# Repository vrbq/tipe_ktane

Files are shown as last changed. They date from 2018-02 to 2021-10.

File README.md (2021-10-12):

# Bomb Defuse Game ! 
### (based on 'Keep Talking And Nobody Explodes')

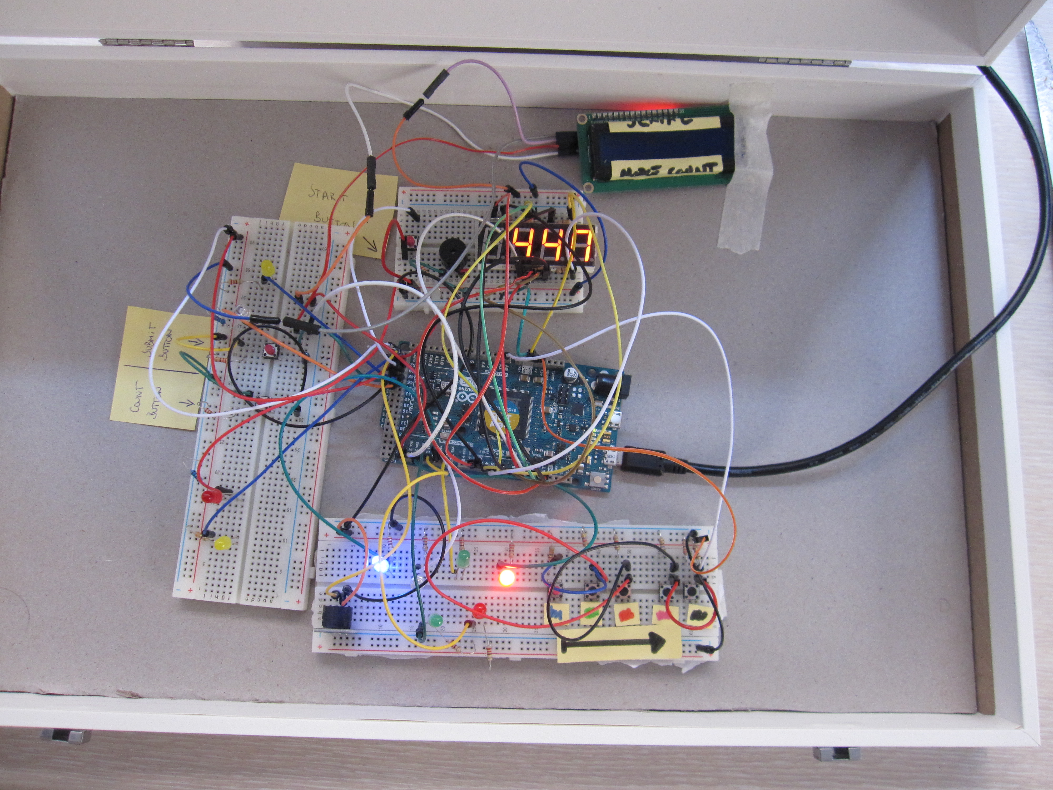
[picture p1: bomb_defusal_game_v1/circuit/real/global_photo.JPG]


## Dependencies

- [AnalogMultiButton](https://github.com/dxinteractive/AnalogMultiButton)
- [LiquidCrystal_I2C](https://github.com/marcoschwartz/LiquidCrystal_I2C)
- [SevSeg](https://github.com/sparkfun/SevSeg)

## Building the circuit

- Global Circuit

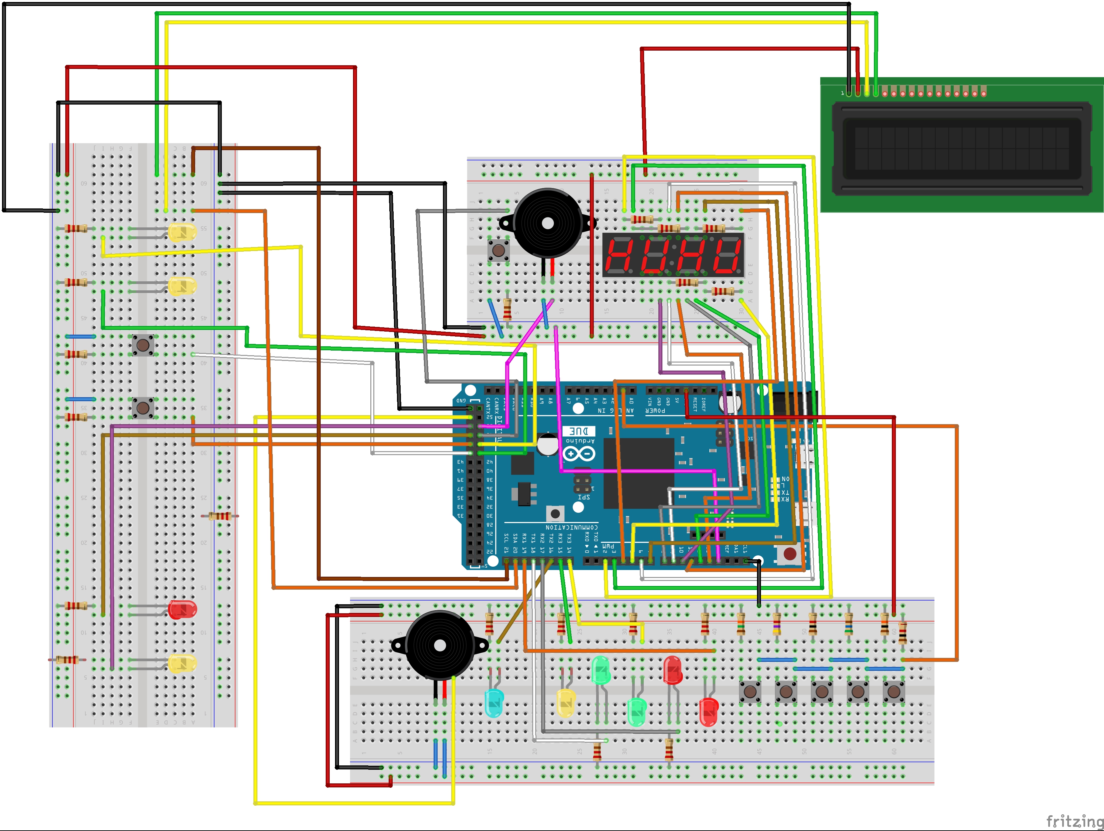
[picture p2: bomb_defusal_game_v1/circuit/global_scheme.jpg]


## Playing

- It's a coop game.

- One player is in front of the bomb but does not see it, while the other communicates the instructions to defuse it.

- For more information, see "manuel" folder.

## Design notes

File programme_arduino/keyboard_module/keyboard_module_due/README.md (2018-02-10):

# Keyboard module for the bomb defuse game

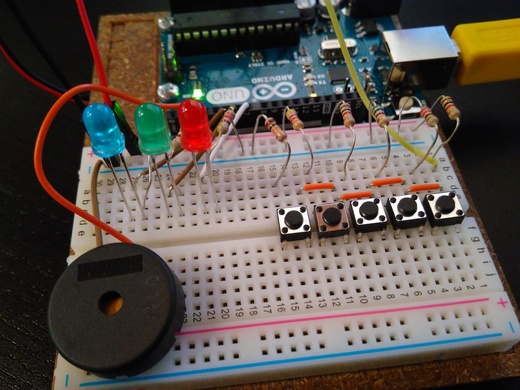
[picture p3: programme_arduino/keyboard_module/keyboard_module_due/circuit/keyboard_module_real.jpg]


A video of the module in action can be found [here](https://youtu.be/Le4A3sgtfqI)!

## Dependencies

- [AnalogMultiButton](https://github.com/dxinteractive/AnalogMultiButton)

## Building the circuit

See the circuit layout in `circuit/circuit.png`.

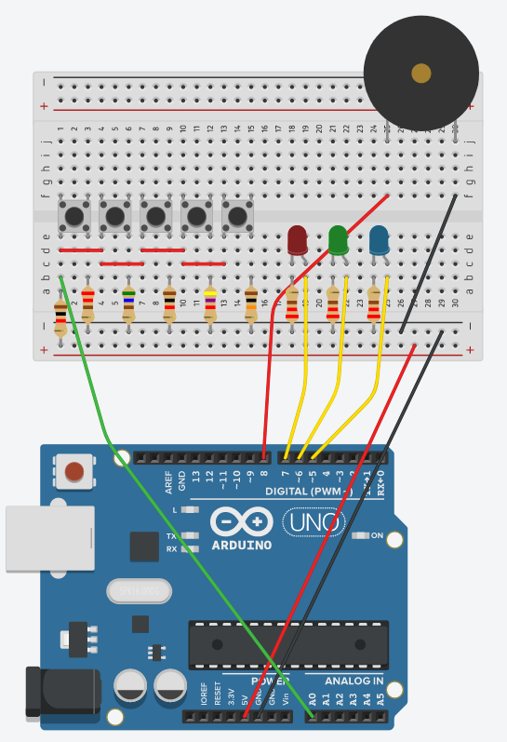
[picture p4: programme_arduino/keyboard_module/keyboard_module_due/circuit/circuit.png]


Alternatively, you can view the circuit on [Tinkercad](https://tinkercad.com). Search for 'defuse_keyboard_module' to find the circuit.

Unfortunately, because the Tinkercad simulator does not allow to import external libraries (AnalogMultiButton in our case), it is not possible to simulate the module there.

## Playing

- At startup, an initialization sequence is played (all LEDs blink sequentially three times in a row).

- A random code is selected in the database (see file `Keyboard.h`), and displayed in coded form to the defuser through a combination of color LEDs.

- A random shift is selected, and displayed in coded form through a combination of color LEDs.

- The defuser has to press every single note in the code correctly, in the right order. If a note is wrong, the red LED will be triggered with a double beep. In that case, the user has to start again from scratch.

## TODO

- Generate documents that indicate the mapping between combinations of color LEDs and code / shift.

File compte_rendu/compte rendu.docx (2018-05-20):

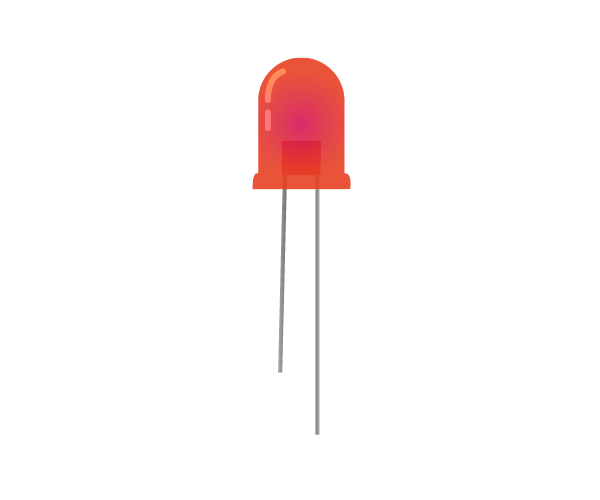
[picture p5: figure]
RÃ©sultat de recherche d'images pour "led"

2017-2018

Rapport de TIPE

NAHMIAZ Thomas REBECQ Victor

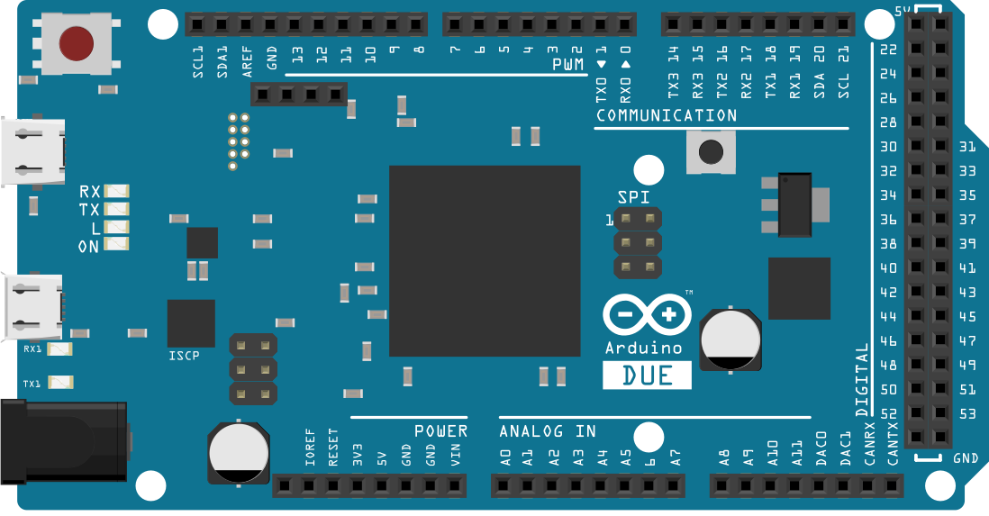
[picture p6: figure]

Est-il possible de faire un jeu sous Arduino ?

PTSI 1

# Résumé :

Le projet proposé est un jeu physique sur Arduino. Le principe est de désamorcer une bombe, en équipe de deux joueurs ou plus. Deux équipes coopéreront lors du jeu :

Le démineur : il peut voir la bombe, interagir avec elle mais ne connait pas le procédé pour désamorcer la bombe.

Les experts : ils possèdent un manuel qui permettra de résoudre les énigmes, mais ne peuvent pas interagir physiquement ou voir la bombe.

Ce jeu est donc purement coopératif, où la communication est primordiale. Les différents mini-jeux doivent être résolus dans un ordre quelconque mais un temps imparti de 5 minutes. Au-delà de ce temps ou si les joueurs font plus de 2 fautes, la bombe explosera.

# Introduction :

Premièrement nous aborderons la mise en place des idées à propos du projet, ses premières maquettes physiques ainsi que les exigences du projet. Puis, nous montrerons comment nous avons procédé pour obtenir plusieurs mini-jeux, jouable en même temps sur Arduino.
Enfin, nous réaliserons un ensemble de tests, et nous évaluerons comment le projet pourra désormais évoluer.

# I. Mise en place :

## Naissance du projet

Dès fin septembre, nous avions trouvé notre projet de TIPE : nous voulions tous les deux faire un jeu, jouable physiquement (avec des boutons, LEDs,…). Après réflexion, et après avoir joué à la version ordinateur de Keep Talking and Nobody Explodes (http://www.keeptalkinggame.com/), nous avons été convaincus que c’est ce jeu que nous voulions adapter physiquement.

Le principe du jeu est simple : 2 joueurs sont en équipe, et doivent désamorcer une bombe, composée d’énigmes. Un joueur voit la bombe, peut interagir avec elle mais ne connait pas la solution aux énigmes (appelés « Modules » dans la suite). L’autre joueur possède le manuel avec la procédure permettant de désamorcer chaque module, mais ne peut ni voir, ni toucher la bombe. C’est ce mélange de jeu coopératif, mêlant tensions et incompréhension, qui nous a montré le potentiel que pouvait avoir ce concept.

## Première maquette

Il fallait désormais prouver que ce concept était viable et réalisable.
Après une première explication orale, nous nous sommes heurtés à un avis plutôt mitigé. En effet, le concept est peut-être facile à comprendre mais il était dur de voir si cette idée pouvait devenir un « jeu », et non rester une banale résolution d’énigme à 2.

Nous avons donc réalisé une maquette en carton de la bombe. Nous avons conçu 4 premiers modules (respectivement le module « Bouton », « Morse », « Accéléromètre » et « Films »).
Un chemin précis (et unique, le jeu était difficilement rejouable) avait été déterminé. Pendant que l’un de nous deux faisait tourner les disques en carton attachés avec des attaches parisiennes, l’autre vérifiait que les modules étaient correctement réalisés, indiquait le temps restant, comptait les erreurs, ... C’est la première prise de conscience que le point important de ce sujet allait être de pouvoir rendre notre programme « multi-tâche ».

Avec cette maquette, nous avons effectué une dizaine d’expérimentations et tiré plusieurs enseignements :

- Premièrement, le jeu n’avait un intérêt que s’il y avait une certaine pression, ajoutée par la limite de temps. Sans elle, le jeu aurait été dénué d’intérêt.
- Ensuite, malgré les défauts apparents d’un tel système, ainsi que la grossièreté de la maquette, chaque groupe de personne testé (avec une limite de temps donc) eu un certain plaisir, une certaine envie de recommencer et de réussir. Cette maquette a d’ailleurs plutôt convaincu M.Delegue (qui faisait équipe avec M. Prachay).

Alors, confiants sur l’avenir du projet, nous nous sommes lancés dans la réalisation du programme.

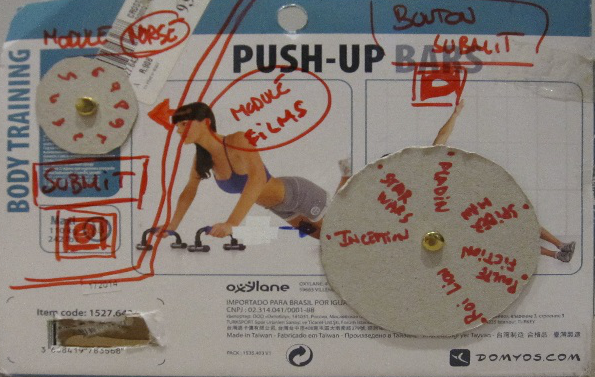
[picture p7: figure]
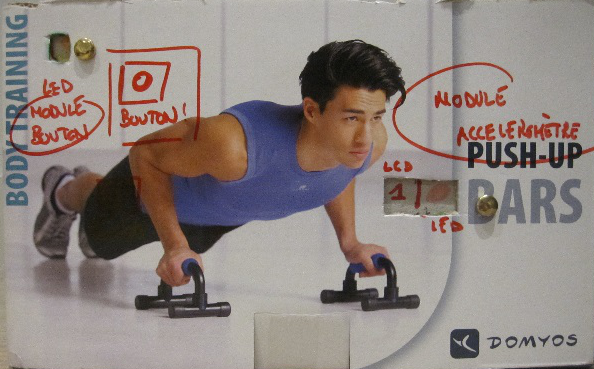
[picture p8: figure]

Figure 1 : Photo de la maquette de la bombe sur une boite en carton

## Lancement du projet, mise en place des exigences

En se basant sur nos idées nous avons conçu le cahier des charges suivant que nous avons suivit tout au long de l’année :

Exigences :

Faire un jeu : Priorité aux interactions entre les joueurs.

Utiliser le minimum d’entrées/sorties.

Gérer plusieurs modules en même temps.

Pouvoir émuler des sons.

Avoir un programme propre.

Pouvoir s’échanger des données facilement pendant le projet (entre concepteurs du projet).

Avoir un manuel propre et intuitif.

Faire un jeu réutilisable, rejouable.

Pouvoir ajouter d’autres modules facilement.

Utiliser un accéléromètre pour donner une vraie dimension physique au jeu.

Nous avons également mis en place un planning tout au long du projet afin de mieux nous organiser. Voir l’annexe 2 pour voir la représentation du planning sous forme de diagramme de GANTT.

# II. Conception :

## Création des modules :

Sans entrer dans une description fastidieuse du mini-jeu et/ou du programme, nous allons brièvement expliquer le principe de chaque module puis expliquer les principaux points de leur réalisation.

Module Keyboard

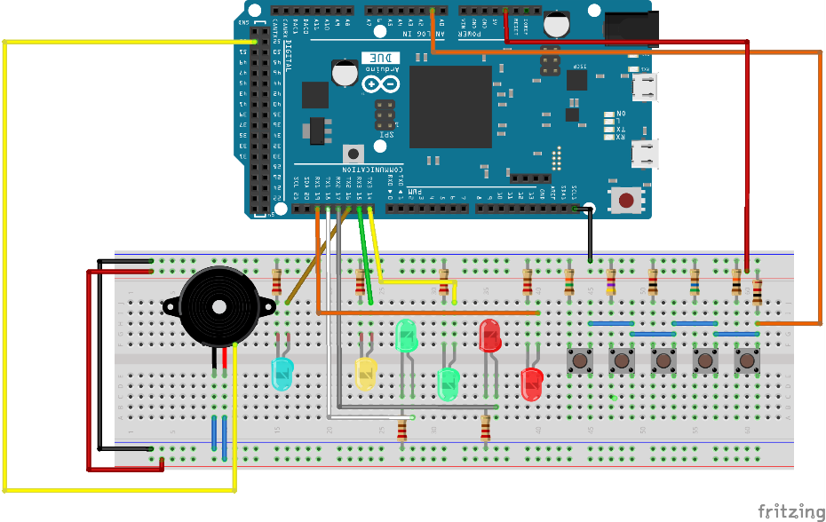
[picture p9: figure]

Figure 2 : Schéma du module Keyboard

Principe : Le démineur doit jouer une séquence précise composée de 9 notes. Les 2 paramètres à prendre en compte sont :

- Le positionnement du « DO », qui peut changer de place parmi les 5 boutons. Cette position est déterminée grâce à un code.
- La séquence à jouer, qui varie selon les couleurs des LEDs allumées.

2 principes assez fondamentaux sont intéressants à détailler ici :

- Emuler un son sous Arduino

Etant sur Arduino DUE (car plus grand nombre d’entrées/sorties )la fonction tone, grandement utilisée sous Arduino UNO ne peut pas être utilisé.

Nous avons donc dû chercher une fonction nous permettant d’émuler un son.

Figure 3 : Comparaison des caractéristiques entre Arduino UNO et DUE

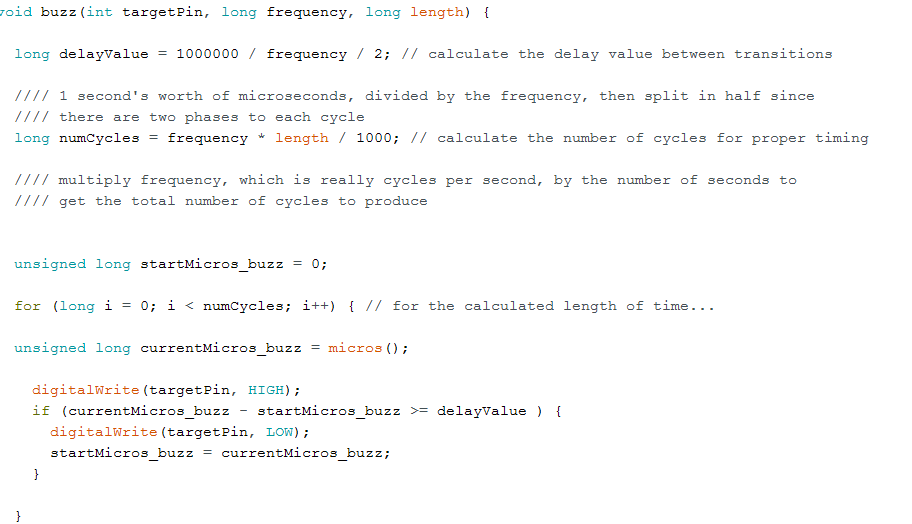
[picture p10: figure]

Figure 4: principe de la programmation du timer

Au-delà de trouver un programme qui fonctionne directement, il est intéressant de comprendre son fonctionnement.

3 attributs sont nécessaires pour cette fonction :

- La sortie du buzzer (buzzer actif, insérer une photo)
- La fréquence jouée (540 Hz pour un LA par exemple)
- La longueur de la note jouée

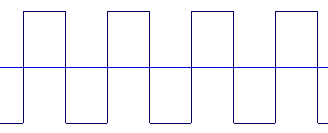
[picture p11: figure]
Résultat de recherche d'images pour "signal carré"

Figure 5 : Signal carré

- Ce programme simule en réalité un signal carré (proche du signal sinusoidal désiré).
- Dans un premier temps, le programme calcule la durée d’une période du signal carré (delayValue).
- Puis est calculé le nombre de cycles (numCycles) qui vont être nécessaire pour jouer le signal carré.
- Le « temps courant », juste avant de rentrer dans la boucle qui va émuler le signal carré, est noté start_Micros_buzz.
- Enfin, on entre dans une boucle qui passe dans l’état « Allumé » dès l’entrée dans cette boucle. Le temps courant est à chaque fois actualisé dans la variable currentMicros_buzz.
- Quand le buzzer aura été allumé plus de temps qu’une période (currentMicros_buzz - start_Micros_buzz >= delayValue) , il ne jouera plus de son. A ce moment, la variable start_Micros_buzz est réinitialisé.
- Cette boucle tournera autant de fois que nécessaire, c’est-à-dire autant de fois que numCycles.
- Boutons branchés en série

Une de nos contraintes étaient d’utiliser le moins d’entrées/sorties possibles. Ayant beaucoup de composants à brancher, nous ne pouvions pas utiliser 5 sorties uniquement pour les boutons. Nous avons donc utilisé une des sorties analogiques de l’arduino, puis branché en série les 5 boutons.

[Sortie 3.3V]

V

[2.2K résistance]

V

[Sortie analogique] --> Bouton 1 --> GND

V

[1K résistance]

+--> Bouton 2 --> GND

V

[1K résistance]

+--> Bouton 3 --> GND

V

[1K résistance]

+--> Bouton 4 --> GND

V

[1K résistance]

+--> Bouton 5 --> GND

Figure 6 : Diagramme d'utilisation d'Analog Multi Button (source : gitHub librairie AnalogMultiButton)

Arduino attribue une valeur analogique aux boutons branchés en série entre 0 et 1023.
Après quelques tests, on peut savoir quel bouton correspond à quelle valeur.
La librairie AnalogMultiButton nous permet alors d’associer ces valeurs à chaque bouton.

Figure 7 : Déclaration des boutons du module « piano »

Module Timer :

Pour ce module, nous avons utilisé un afficheur 7 segments

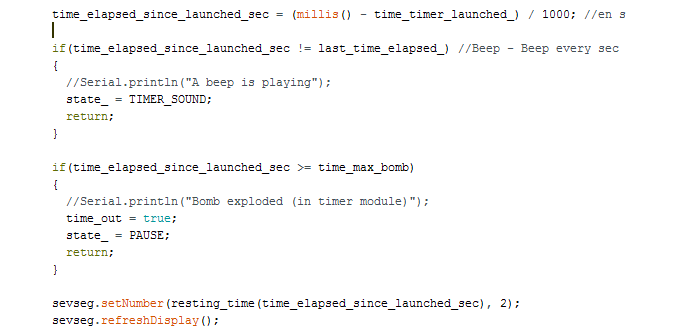
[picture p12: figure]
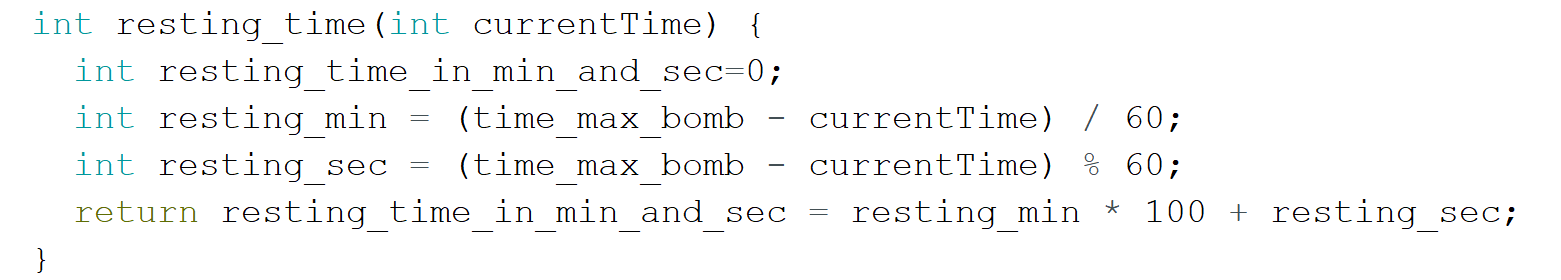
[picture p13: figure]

Figure 8 : Principes de la programmation du timer

Dès que la bombe est lancée, le temps courant est sauvegardé dans la variable time_timer_launched.
Ainsi est calculée le temps depuis lequel la bombe a été lancée (time_elapsed_since_launched_sec).
Avec une boucle Tant Que, on limite le temps d’écoulement du timer avec la variable préalablement définie time_max_bomb.

Enfin, l’afficheur 7 segment est rafraichi et affiche continuellement le temps restant. La fonction resting_time permet de séparer les minutes et les secondes, pour afficher ces 2 éléments distinctement sur l’afficheur.

Module Morse :

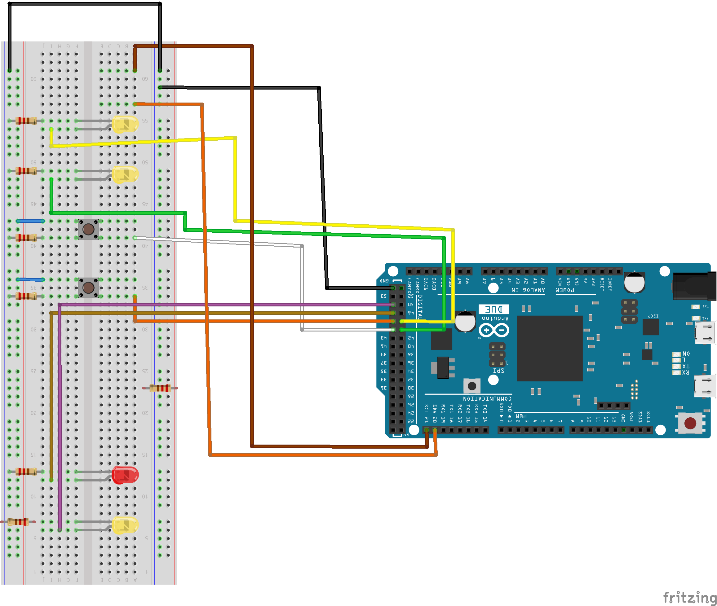
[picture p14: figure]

Principe: Le joueur devant la bombe doit communiquer des signaux qu’il voit en morse afin que l’autre joueur déchiffre le bon mot parmi neufs possibles.

Les mots sont directement convertis dans le programme afin de pouvoir changer facilement de mot sans erreurs. La fonction ToUpperCase transcrit les mots en majuscules pour avoir moins de lettres à coder, ensuite la fonction replace change toutes les lettres en suites de « . » et « - » selon le langage morse français. Il ne reste plus qu’à traduire les mots en signaux lumineux grâce à, entre autres, la fonction millis détaillée plus loin.

Figure 9 : Schéma du module Morse

Nous avons utilisé la commande switch case pour choisir le mot en fonction de la valeur apportée par la commande Randomseed : l’avantage de cette commande par rapport à un if .. else est de raccourcir et clarifier nettement la syntaxe.

Rebond du bouton :

L’appui sur un bouton poussoir peut ne pas transmettre qu’un seul contact mais plusieurs, dépendant de la qualité du bouton.

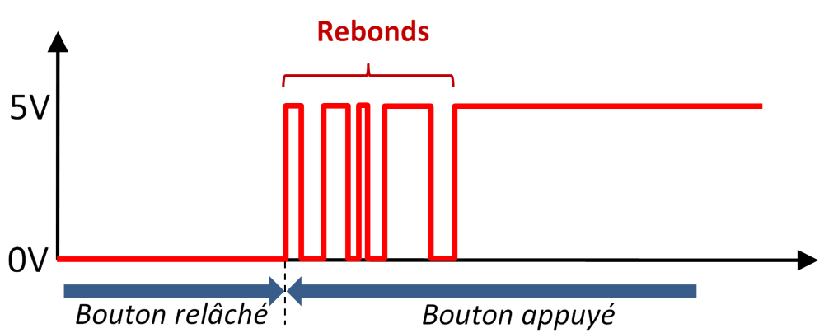
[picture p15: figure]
RÃ©sultat de recherche d'images pour "rebond bouton poussoir"

Figure 10: Schéma du signal émis par le rebond d'un bouton

Il y’a deux façons de résoudre ce problème :

Utiliser un condensateur en parallèle pour adoucir le passage transitoire ou attendre logiciellement un court instant (250 millisecondes) avant le décompte d’un autre appui sur le bouton pour être sûr de ne pas prendre en compte les rebonds. C’est la deuxième solution qui a été choisie.

Module accéléromètre

Il était prévu mais n’a pas été intégré dans le projet, faute de temps. Le joueur devait bouger un cube en fonction des indications de l’autre joueur. Ce module aurait rajouté une véritable dimension physique au jeu par rapport à un jeu virtuel. L’intention initiale était de faire des translations du cube dans l’espace. Or l’accéléromètre ne relève que l’accélération et l’orientation dans l’espace. Il n’était pas possible de relever avec précision les mouvements effectués. Nous avions donc adapté le manuel du démineur afin que le joueur doive effectuer des rotations du cube ce que l’accéléromètre permettait de faire avec plus de précision.

Une bibliothèque Arduino est dédiée à l’accéléromètre. Après avoir inclus la bibliothèque et initialisé l’accéléromètre il suffit de relever les valeurs relevées par celui-ci. Le joueur aurait dû mettre le cube dans la position indiquée par le manuel et appuyer sur un bouton pour relever la valeur des positions selon les axes X, Y et Z.

## Gérer plusieurs modules en même temps :

Voici la partie la plus compliquée que nous ayons eu à réaliser.

La fonction delay est une fonction bloquante qui ne permet pas d’effectuer plusieurs tâches en parallèle. Ainsi, à chaque émulation de son le programme se gelait entièrement (l’afficheur 7 segments était principalement impacté). Nous avons donc opté pour l’utilisation de la fonction millis qui gère le temps sans être une fonction bloquante selon le modèle :

Pour expliquer ce concept, voici un programme non bloquant :

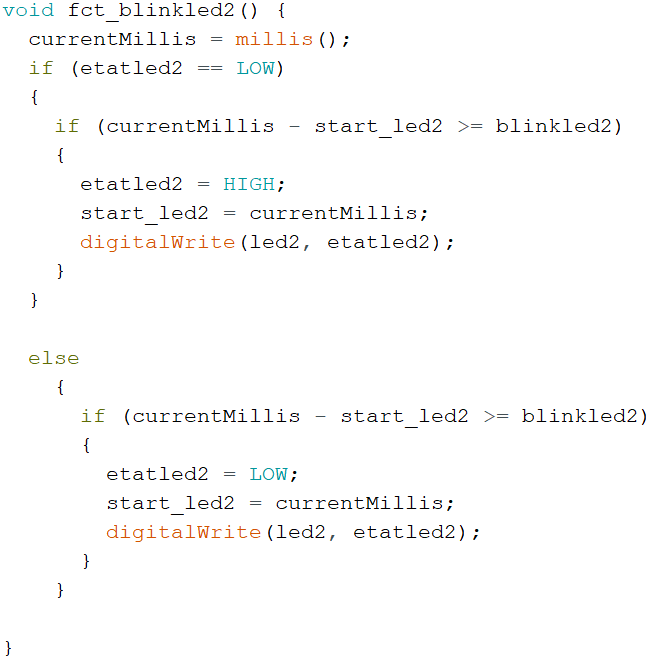
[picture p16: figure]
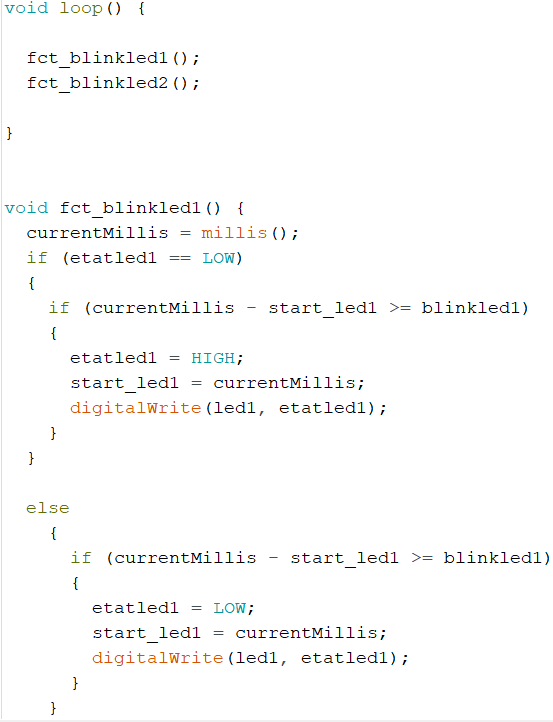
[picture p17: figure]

Figure 11 : Programme de deux Leds clignotant de manière désynchronisée

Ici, les 2 LEDs clignotent de manière complètement indépendante. Avec la fonction delay, il serait impossible de réaliser un tel programme.

Pour réaliser cela, nous avons contacté Henri Rebecq, frère de Victor, ingénieur diplômé de l’école Paris Telecom et travaillant actuellement sur sa thèse à l’ETH de Zurich. Nous n’avions aucune idée de comment réaliser cet assemblage de tous les modules, autant logiquement que techniquement (le langage Arduino étant proche du C, langage que nous ne connaissons pas bien).

Pour utiliser cette fonction millis, le programme a donc besoin de savoir – à chaque instant – dans quel état il se situe.

Pour cela, Henri nous a conseillé de réaliser une machine à état. Nous allons ici voir un exemple sur le module « Piano », sachant que les autres modules ont été réalisé d’une manière similaire (par souci de cohérence du programme).

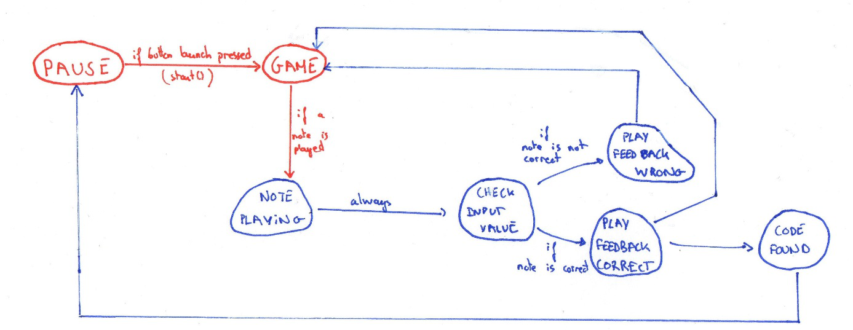
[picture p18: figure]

Figure 12 : Diagramme d'états du module Keyboard

Selon le diagramme ci-dessus, nous avions donc défini plusieurs états :

- PAUSE : état initial du module. Lorsque la fonction reset est appelé (par l’appui d’un bouton par exemple), l’état passe à GAME.
- GAME : état principal, où l’appui sur un bouton est détecté. Plusieurs sous-états se suivent :
  - NOTE_PLAYING : suit directement l’état GAME ; permet de jouer directement la note correspondant au bouton venant d’être appuyé
  - CHECK_INPUT_VALUE : traite l’entrée du bouton (entrée correcte ou fausse).
  - PLAY_FEEDBACK_CORRECT : allume une LED verte.
  - PLAY_FEEDBACK_WRONG : allume une LED rouge et recommence le code à zéro.
  - CODE_FOUND : Le jeu revient à son état initial (PAUSE)

Le même principe a été appliqué pour le module « Morse ou « Timer ». (voir annexe 2).

La fonction attachInterrupt permet d’arriver au même résultat. A chaque appui sur un bouton celle-ci effectue une tâche en priorité sur les autres. Cette fonction n’est cependant pas durable sur des programmes longs et ne peut pas être utilisée un grand nombre de fois en tant qu’une seule fonction ne peut être appelée dans le même temps.

Henri nous a aussi conseillé d’améliorer la lisibilité de notre programme. Pour cela, nous avons mis nos variables dans la même casse : en anglais, sans majuscule, avec un underscore. Nous avons aussi réalisé nos modules dans la même idée (machines à états appelant les mêmes états principaux : PAUSE et GAME).

## Faire un jeu réutilisable :

### Solutions :

Nous avons décidé d’utiliser des valeurs aléatoires et de programmer plusieurs chemins possibles en fonctions de ces valeurs pour que le jeu présente différents cas et qu’ainsi les parties de soient pas répétitives. Ces différents chemins se feront directement à l’intérieur du module comme pour le morse ou au travers du numéro de série. Les chemins changent à chaque redémarrage de la carte pour proposer des parties différentes.

### Mise en œuvre :

Nous avons utilisé la fonction random(min, max) pour générer des variables aléatoires. Il est à noter que la valeur minimale est incluse et que la valeur maximale est exclue, c’est pourquoi dans le module morse pour neuf mots nous avons pris la valeur alea = random(1,10).

La fonction random ne génère qu’une valeur aléatoire par téléversement, et non pas à chaque redémarrage de la carte. Nous avons donc rajouté la fonction randomSeed(analogRead(0)) qui lit une grandeur physique sur la sortie 0 qui n’est branchée à rien. Cette fonction permet de générer une valeur aléatoire différente à chaque mise sous tension de la carte en plus d’obtenir des valeurs plus aléatoires.

## Outils informatiques utilisés :

Nous avons utilisé le site d’échange de données GitHub afin de réunir les programmes et autres fichiers dans un dossier en ligne. Cela permet le partage des programmes et d’autres fichiers afin de les ouvrir sur n’importe quel ordinateur ayant les droits d’accès au projet. Notre projet sur Github :

https://github.com/trickart73/tipe_ktane/tree/master/bomb_defusal_game_v1

Le logiciel Fritzing pour réaliser les schémas du projet, ce logiciel permet également de simuler un projet et de créer les plans en circuit imprimé. Un schéma du circuit est essentiel pour pouvoir communiquer aux autres comment comprendre et réaliser un certain programme.

Nous avons aussi utilisé l’hébergeur de vidéos YouTube pour partager les vidéos de test.

Enfin nous avons évidemment utilisé Arduino pour la programmation du projet

# III. Exploitation

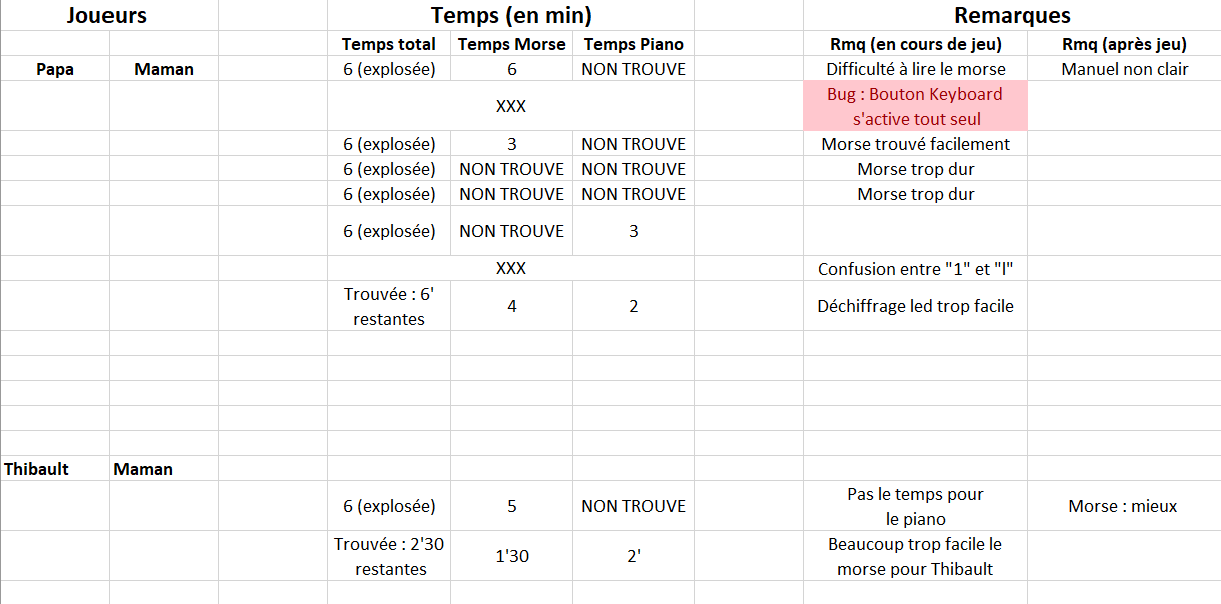
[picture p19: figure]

Nous avons réalisé plus d’une vingtaine de tests avec des binômes de personnes différente. Il a fallu au début trouver le juste milieu au niveau de la difficulté et corriger les bugs rencontrés.

Figure 13 : Compte rendu des premières parties jouées

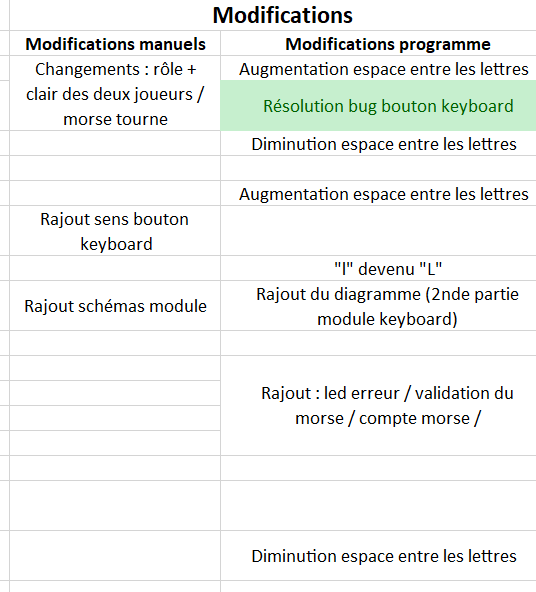
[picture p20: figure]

Nous voyons bien qu’au fur et à mesure des parties, les joueurs progressent.

Toutefois, les joueurs ayant testé le jeu ont été satisfaits et ont ressenti la frustration de la défaite des premières parties, leur donnant envie de rejouer.

Il est aussi important de noter que depuis ces 10 premières tentatives – où de nombreuses modifications ont été apportées au projet – aucun bogue (venant du programme ou de la conception des manuels) n’a été constaté. En effet, sur les 20 tentatives suivantes, le seul problème que nous ayons eu est un débranchement de fils (dû aux grands nombres de connexions).

Nous avons filmé le premier essai de M. Lanoix devant la bombe (disponible ici : https://www.youtube.com/watch?v=MbPvuHy70Hc&feature=youtu.be )

Figure 14 : Modifications apportées suites aux tests

# Conclusion :

Le cahier des charges du projet a en grande partie été rempli. Le jeu est désormais opérationnel.

Les cartes Arduino regorgent de possibilités et sont donc un bon support pour ce projet. En plus d’avoir une grande communauté, les accessoires électroniques sont peu chers et permettent de réaliser des maquettes facilement. Les cartes Arduino ont une grande capacité de calcul et de stockage étant donné que le code ne prend que très peu d’espace. Le programme que nous avons conçu n’occupe que 7% de la mémoire de la carte et permet donc un large développement du projet ultérieurement.

Pour finir, que peux devenir le projet ? Aujourd’hui, nous avons un jeu fonctionnel, comprenant 2 modules. Le jeu est grandement réutilisable avant de devenir facile.
De plus, nous avons réalisé l’ensemble des modules selon la même architecture, en utilisant des classes. Sans rentrer dans les détails de conception, cela nous a permis d’obtenir un fichier « main » court et propre, idéal de tout programme. Les autres modules sont réalisés dans des fichiers à part (les « headers », avec pour extension « .h »).

Nous pouvons donc rajouter facilement des modules, à l’unique condition qu’ils ne soient pas bloquants !
Dans la conception en elle-même, Arduino reste un prototypage, avec des plaques d’essais. Nous pourrions facilement envisager de remplacer chaque module par un circuit imprimé, qui peut facilement se rajouter au jeu. Nous pourrions aussi rajouter une boîte plus adaptée, ou encore une batterie externe, ou un système de difficulté (Facile ou Difficile), car nous avons remarqué durant les phases tests que la difficulté n’était pas ressentie de la même manière pour un étudiant en sciences qu’un étudiant en lettres (des calculs parfois conséquents peuvent être effectués).

Enfin, si nous décidons d’améliorer ce TIPE par la suite, nous pourrions aussi le porter sur Arduino UNO (avec l’aide d’un 74HC595, permettant de démultiplier le nombre de sorties/entrées sur l’Arduino). Techniquement parlant, l’Arduino Uno serait largement capable de recevoir et d’exécuter un tel programme.
L’ultime étape serait d’utiliser un microcontrôleur (chipset) : l’Arduino ne deviendrait alors utile que pour téléverser le programme (interface chipset / ordinateur).

## Remerciements

Nous remercions bien évidemment nos 2 professeurs, M. Lanoix et M. Delegue, qui nous ont guidé tout du long de ce projet. Un grand merci à Henri Rebecq, sans qui nous n’aurions pu réaliser ce projet tant son aide a été précieuse. Les connaissances qu’il nous as transmises - tant la logique et le raisonnement de construction d’un programme complexe, que des outils techniques comme les classes – nous seront certainement utile pour le reste de nos années de programmeur. Un merci aux parents (qui ont toujours été les premiers testeurs de versions pas toujours très abouties) et à tous ceux qui ont pu tester le jeu, leurs retours sont indispensables à l’amélioration du jeu.

# Bibliographie :

- CFaury, « Le bouton poussoir », http://arduino.blaisepascal.fr/index.php/2017/11/30/le-bouton-poussoir/, 02/18
- WMLogistic, « Code Morse avec une Led », https://forum.arduino.cc/index.php?topic=492308.0, 12/17
- TamiaLab, « Faire plusieurs choses à la fois avec une carte Arduino », https://www.carnetdumaker.net/articles/faire-plusieurs-choses-la-fois-avec-une-carte-arduino/, 03/18
- David LeGall, « Un minuteur à base d'Arduino », http://wikifab.org/wiki/Timer_:_Un_minuteur_%C3%A0_base_d%27Arduino, 11/17
- Coding Badly, « The reliable but not very sexy way to seed random », http://forum.arduino.cc/index.php/topic,66206.0.html, 01/18
- Rob Faludi, « Buzzer Arduino Example Code », https://www.faludi.com/2007/04/23/buzzer-arduino-example-code/, 12/17
- Dxinteractive, « AnalogMultiButton », https://github.com/dxinteractive/AnalogMultiButton, 01/18

# Annexes

Annexe 1

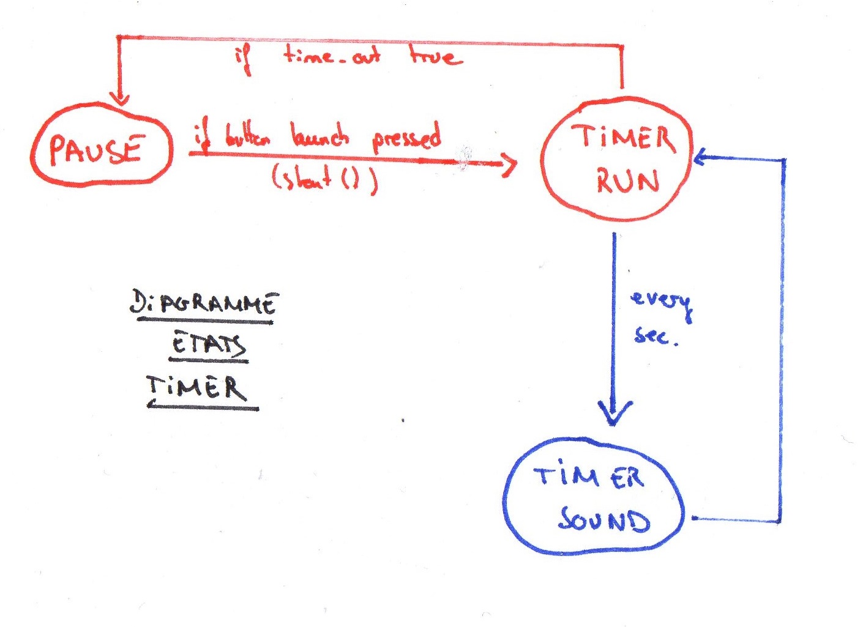
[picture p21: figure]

Figure 15 : Diagramme d'états Timer

Annexe 2 :

Figure 16: Planning (GANTT)

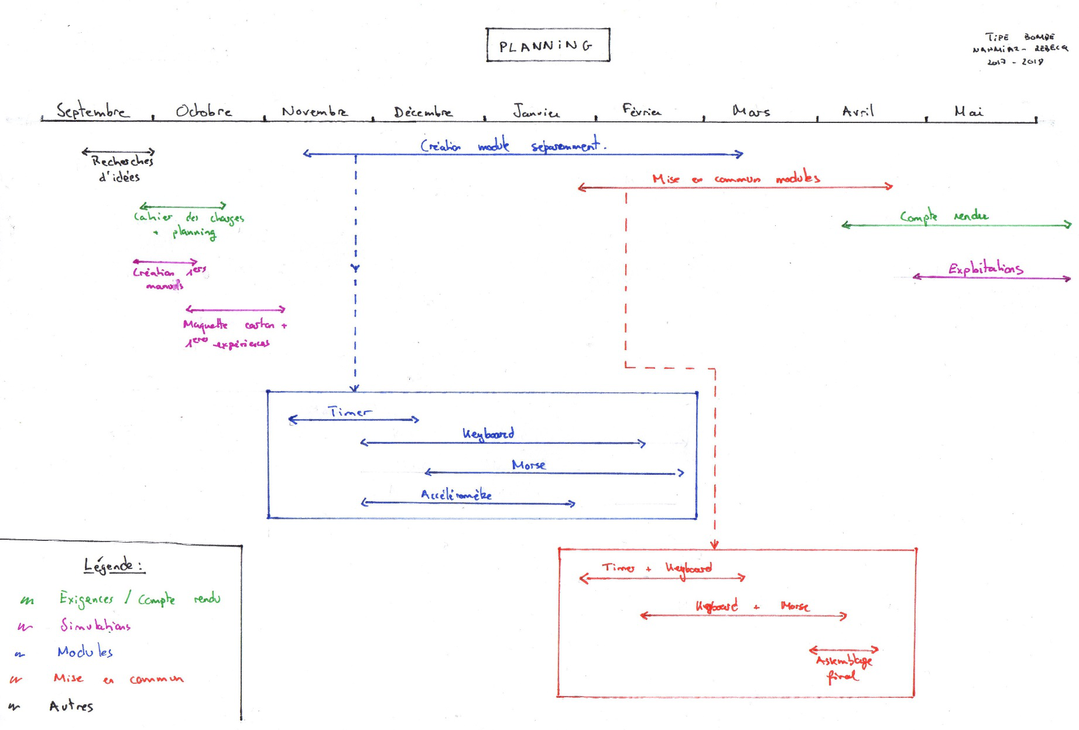
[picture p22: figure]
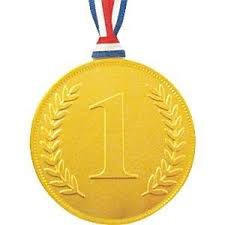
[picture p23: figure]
C:\Users\Vic\AppData\Local\Microsoft\Windows\Temporary Internet Files\Content.MSO\58AD7BD0.tmp

Annexe 3 :

Clémence Potin & Antoine Vermorel

(temps restant : 52 secondes)

A l’heure actuelle, un seul duo à réussi à désamorcer la bombe en 5 minutes dans les conditions suivantes :

- Pas de triche
- Aucune aide des créateurs du jeu

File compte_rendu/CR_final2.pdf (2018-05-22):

# 2017-2018 Rapport de TIPE NAHMIAZ Thomas, REBECQ Victor

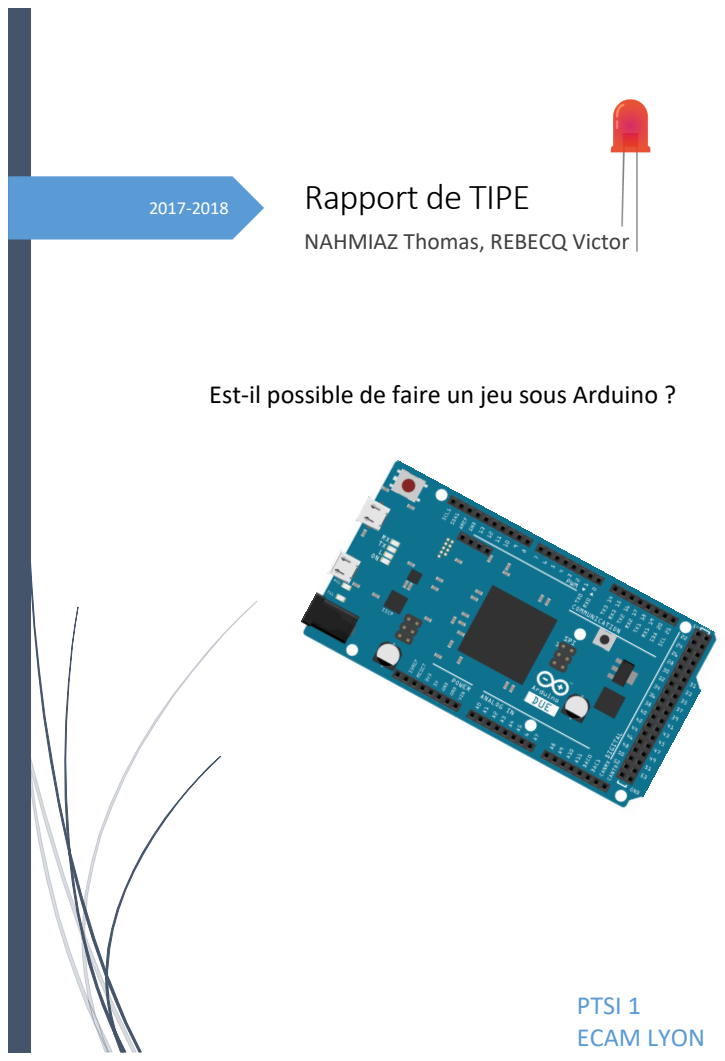
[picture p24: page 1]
PTSI 1 ECAM LYON

Est-il possible de faire un jeu sous Arduino ?

TIPE 2017-2018

## Table des matières

## Résumé :

Le projet proposé est un jeu physique sur Arduino. Le principe est de désamorcer une bombe, en équipe de deux joueurs ou plus. Deux équipes coopéreront lors du jeu :

- Le démineur : il peut voir la bombe, interagir avec elle mais ne connaît pas le procédé pour désamorcer la bombe.
- Les experts : ils possèdent un manuel qui permettra de résoudre les énigmes, mais ne peuvent pas interagir physiquement ou voir la bombe.

Ce jeu est donc purement coopératif, et la communication est primordiale. Les différents mini-jeux doivent être résolus dans un ordre quelconque mais dans un temps imparti de 5 minutes. Au-delà de ce temps ou si les joueurs font plus de 2 fautes, la bombe explosera.

## Introduction :

Premièrement nous aborderons la mise en place des idées à propos du projet, ses premières maquettes physiques ainsi que les exigences du projet. Puis, nous montrerons comment nous avons procédé pour obtenir plusieurs mini-jeux, jouables en même temps sur Arduino. Enfin, nous réaliserons un ensemble de tests, et nous évaluerons comment le projet pourra désormais évoluer.

## I. Mise en place :

Naissance du projet

Dès fin septembre, nous avions trouvé notre projet de TIPE : nous voulions tous deux faire un jeu, jouable physiquement (avec des boutons, LEDs, …). Après réflexion, et après avoir joué à la version ordinateur de Keep Talking and Nobody Explodes, (http://www.keeptalkinggame.com/) nous avons été convaincus que c’est ce jeu que nous voulions adapter physiquement.

Le principe du jeu est simple : 2 joueurs sont en équipe, et doivent désamorcer une bombe, composée d’énigmes. Un joueur voit la bombe, peut interagir avec elle mais ne connaît pas la solution aux énigmes (appelés « Modules » par la suite). L’autre joueur possède le manuel avec la procédure permettant de désamorcer chaque module, mais ne peut ni voir, ni toucher la bombe. C’est ce mélange de jeu coopératif, mêlant tensions et incompréhensions, qui nous a montré le potentiel que pouvait avoir ce concept.

Première maquette

Il fallait désormais prouver que ce concept était réalisable. Après une première explication orale, nous nous sommes heurtés à un avis plutôt mitigé. En effet, le concept est peut-être facile à comprendre mais il était difficile de voir si cette idée pouvait devenir un « jeu », et non rester une banale résolution d’énigme à 2.

Nous avons donc réalisé une maquette en carton de la bombe. Nous avons conçu 4 premiers modules (respectivement le module « Bouton », « Morse », « Accéléromètre » et « Films »). Un chemin précis (et unique, le jeu était difficilement rejouable) avait été déterminé. Pendant que l’un de nous deux faisait tourner les disques en carton attachés avec des attaches parisiennes, l’autre vérifiait que les modules étaient correctement réalisés, indiquait le temps restant, comptait les erreurs, … Nous nous sommes rendu compte que la difficulté de ce sujet allait être de pouvoir rendre notre programme « multi-tâches ».

Avec cette maquette, nous avons effectué une dizaine d’expérimentations et tiré plusieurs enseignements :

- Premièrement, le jeu n’avait un intérêt que s’il y avait une certaine pression, ajoutée par la limite de temps. Sans elle, le jeu aurait été dénué d’intérêt.
- Ensuite, malgré les défauts apparents d’un tel système, ainsi que la grossièreté de la maquette, chaque groupe de personnes testé (avec une limite de temps donc) eut un certain plaisir, une certaine envie de recommencer et de réussir. Cette maquette a d’ailleurs plutôt convaincu M.Delegue (qui faisait équipe avec M. Prachay).

Alors, confiants sur l’avenir du projet, nous nous sommes lancés dans la réalisation du programme.

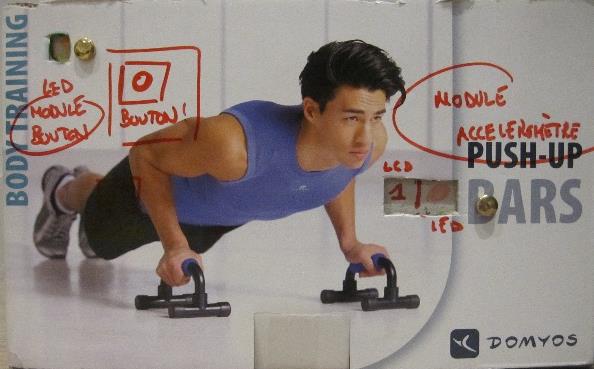
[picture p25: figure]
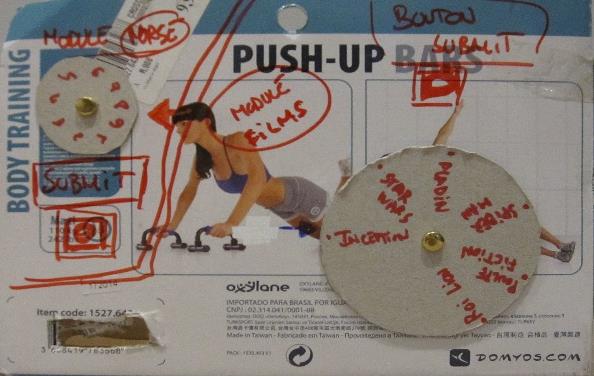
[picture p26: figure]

Figure 1 : Photo de la maquette de la bombe sur une boite en carton

Lancement du projet, mise en place des exigences

En se basant sur nos idées nous avons conçu le cahier des charges suivant que nous avons suivi tout au long de l’année :

Exigences :

Concevoir un jeu : Priorité aux interactions entre les joueurs. Utiliser le minimum d’entrées/sorties.

Gérer plusieurs modules en même temps.
Pouvoir émuler des sons.
Avoir un programme propre et compréhensible

Pouvoir s’échanger des données facilement pendant le projet (entre concepteurs du projet). Avoir un manuel intuitif.

Réaliser un jeu rejouable.
Pouvoir ajouter d’autres modules facilement.

Utiliser un accéléromètre pour apporter une vraie dimension physique au jeu.

Nous avons également mis en place un planning en début de projet afin de mieux nous organiser. Voir l’annexe 2 pour voir la représentation du planning sous forme de diagramme de GANTT.

## II. Conception :

Création des modules :

Sans entrer dans une description fastidieuse du mini-jeu et/ou du programme, nous allons brièvement expliquer le principe de chaque module puis expliquer les principaux points de leur réalisation.
Module Keyboard

Figure 2 : Schéma du module Keyboard


Principe : Le démineur doit jouer une séquence précise composée de 9 notes. Les deux paramètres à prendre en compte sont :

- Le positionnement du « DO », qui peut changer de place parmi les 5 boutons. Cette position est déterminée grâce à un code.
- La séquence à jouer, qui varie selon les couleurs des LEDs allumées.

Deux principes assez fondamentaux sont intéressants à détailler ici :

- Emuler un son sous Arduino

Etant sur Arduino DUE (car plus grand nombre d’entrées/sorties) la fonction tone, fonctionnant sous Arduino UNO, n’est pas implémentée sur la version DUE.

Nous avons donc dû chercher une fonction nous permettant d’émuler un son.


Figure 3 : Comparaison des caractéristiques entre Arduino UNO et DUE


Figure 4: principe de la programmation du timer

Au-delà de trouver un programme qui fonctionne directement, il est intéressant de comprendre son fonctionnement.

3 attributs sont nécessaires pour cette fonction :

- La sortie du buzzer (buzzer actif, insérer une photo)
- La fréquence jouée (440 Hz pour un LA par exemple)
- La longueur de la note jouée

- Ce programme simule en réalité un signal carré (proche du signal sinusoidal désiré).
- Dans un premier temps, le programme calcule
la durée d’une période du signal carré
(delayValue).

Figure 5 : Signal carré

- Puis est calculé le nombre de cycles (numCycles) qui vont être nécessaires pour jouer le signal carré.
- Le « temps courant », juste avant de rentrer dans la boucle qui va émuler le signal carré, est noté start_Micros_buzz.
- Enfin, on entre dans une boucle qui passe dans l’état « Allumé » dèsl’entrée dans cette boucle. Le temps courant est à chaque fois actualisé dans la variable currentMicros_buzz.
- Quand le buzzer aura été allumé plus de temps qu’une période (currentMicros_buzz -start_Micros_buzz >= delayValue), il ne jouera plus de son. A ce moment, la variable start_Micros_buzz est réinitialisée.
- Cette boucle tournera autant de fois que nécessaire, c’est-à-dire autant de fois que numCycles.
- Boutons branchés en série

Une de nos contraintes était d’utiliser le moins d’entrées/sorties possible. Ayant beaucoup de composants à brancher, nous ne pouvions pas utiliser 5 sorties uniquement pour les boutons. Nous avons donc utilisé une des sorties analogiques de l’Arduino, puis branché en série les 5 boutons.

[Sortie 3.3V]
V
[2.2K résistance]
V
[Sortie analogique] --> Bouton 1 --> GND |
V
[1K résistance]
+--> Bouton 2 --> GND
V
[1K résistance]
+--> Bouton 3 --> GND
V
[1K résistance]
+--> Bouton 4 --> GND
V
[1K résistance]
+--> Bouton 5 --> GND
Figure 6 : Diagramme d'utilisation de la librairie AnalogMultiButton (source : gitHub librairie AnalogMultiButton)

Arduino attribue une valeur analogique aux boutons branchés en série entre 0 et 1023. Après quelques tests, on peut savoir quel bouton correspond à quelle valeur. La librairie AnalogMultiButton nous permet alors d’associer ces valeurs à chaque bouton.

Figure 7 : Déclaration des boutons du module « piano »

Module Timer :

Pour ce module, nous avons utilisé un afficheur 7 segments


Figure 8 : Principes de la programmation du timer

Dès que la bombe est lancée, le temps courant est sauvegardé dans la variable time_timer_launched.
Ainsi le temps à partir duquel la bombe a été lancée est calculé dans la variable time_elapsed_since_launched_sec.
On limite le temps d’écoulement du timer avec la variable préalablement définie time_max_bomb. Si time_elapsed_since_launched_sec > time_max_bomb, la bombe explose.

Enfin, l’afficheur 7 segments est rafraîchit et affiche continuellement le temps restant. La fonction resting_time permet de séparer les minutes et les secondes, pour afficher ces 2 éléments distinctement sur l’afficheur.
Module Morse :


Principe : Le joueur devant la bombe doit communiquer des signaux lumineux qu’il voit en morse afin que l’autre joueur déchiffre le bon mot parmi les neuf possibles.

Les mots sont directement convertis dans le programme afin de pouvoir changer facilement de mot sans erreurs. La fonction ToUpperCase transcrit les mots en majuscules pour avoir moins de lettres à coder, ensuite la fonction replace change toutes les lettres en suites de « . » et « - » selon le langage morse français. Il ne reste plus qu’à traduire les mots en signaux lumineux grâce à, entre autres, la fonction millis détaillée plus loin.

Nous avons utilisé la commande switch case pour choisir le mot en fonction de la valeur apportée par la commande Randomseed : l’avantage de cette commande par rapport à un if ... else est de raccourcir et clarifier nettement la syntaxe.

- Rebond du bouton :

L’appui sur un bouton poussoir peut ne pas transmettre qu’un seul contact mais plusieurs, dépendant de la qualité du bouton.


Figure 10: Schéma du signal émis par le rebond d'un bouton

Il y a deux façons de résoudre ce problème :

Figure 9 : Schéma du module Morse

- Utiliser un condensateur en parallèle pour adoucir le passage transitoire.
- Attendre logiciellement un court instant (250 millisecondes) avant le décompte d’un autre appui sur le bouton pour être sûr de ne pas prendre en compte les rebonds.

C’est la deuxième solution qui a été choisie.
Module Accéléromètre

Il était prévu mais n’a pas été intégré dans le projet, faute de temps. Le joueur devait bouger un cube en fonction des indications de l’autre joueur. Ce module aurait rajouté une véritable dimension physique au jeu par rapport à un jeu virtuel. L’intention initiale était de faire des translations du cube dans l’espace. Or l’accéléromètre ne relève que l’accélération et l’orientation dans l’espace. Il n’était pas possible de relever avec précision les mouvements effectués. Nous avions donc adapté le manuel du démineur afin que le joueur doive effectuer des rotations du cube ce que l’accéléromètre permettait de faire avec plus de précision.

Une bibliothèque Arduino est dédiée à l’accéléromètre. Après avoir inclus la bibliothèque et initialisé l’accéléromètre, il suffit de relever les valeurs données par celui-ci. Le joueur aurait dû mettre le cube dans la position indiquée par le manuel et appuyer sur un bouton pour relever la valeur des positions selon les axes X, Y et Z.

Gérer plusieurs modules en même temps :

Voici la partie la plus compliquée que nous ayons eu à réaliser.

La fonction delay est une fonction bloquante qui ne permet pas d’effectuer plusieurs tâches en parallèle. Ainsi, à chaque émulation de son le programme se gelait entièrement (l’afficheur 7 segments était principalement impacté). Nous avons donc opté pour l’utilisation de la fonction millis qui gère le temps sans être une fonction bloquante.

Pour expliquer ce concept, voici un programme non bloquant :


Figure 11 : Programme de deux Leds clignotant de manière désynchronisée

Ici, les 2 LEDs clignotent de manière complètement indépendante. Avec la fonction delay, il serait impossible de réaliser un tel programme.

Pour réaliser un programme « multi-tâches », nous avons contacté Henri Rebecq, frère de Victor, thésard à l’ETH/Université de Zürich. (https://www.ethz.ch/en.html) Nous n’avions aucune idée de comment réaliser cet assemblage de tous les modules, autant logiquement que techniquement (le langage Arduino étant proche du C, langage que nous ne connaissons pas bien).

Pour utiliser cette fonction millis, le programme a donc besoin de savoir – à chaque instant – dans quel état il se situe.

Pour cela, Henri nous a conseillé de réaliser une machine à état. Nous allons ici voir un exemple sur le module « Piano », sachant que les autres modules ont été réalisé d’une manière similaire (par souci de cohérence du programme).


Figure 12 : Diagramme d'états du module Keyboard

Selon le diagramme ci-dessus, nous avions donc défini plusieurs états :

- PAUSE : état initial du module. Lorsque la fonction reset est appelé (par l’appui d’un bouton par exemple), l’état passe à GAME.
- GAME : état principal, où l’appui sur un bouton est détecté. Plusieurs sous-états se suivent :
- NOTE_PLAYING : suit directement l’état GAME ; permet de jouer directement la note correspondant au bouton venant d’être appuyé.
- CHECK_INPUT_VALUE : traite l’entrée du bouton (entrée correcte ou fausse).
- PLAY_FEEDBACK_CORRECT : allume une LED verte.
- PLAY_FEEDBACK_WRONG : allume une LED rouge et recommence le code à zéro.
- CODE_FOUND : le jeu revient à son état initial (PAUSE)

Le même principe a été appliqué pour le module « Morse ou « Timer ». (Voir annexe 1).

La fonction attachInterrupt permet d’arriver au même résultat. A chaque appui sur un bouton celle-ci effectue une tâche en priorité sur les autres. Cette fonction n’est cependant pas durable sur des programmes longs. Elle ne peut pas être utilisée un grand nombre de fois car appelée, elle devient totalement prioritaire sur le reste du programme.

Henri nous a aussi conseillé d’améliorer la lisibilité de notre programme. Pour cela, nous avons mis nos variables dans la même casse : en anglais, en minuscule, avec un underscore. Nous avons aussi réalisé nos modules dans la même idée (machines à états appelant les mêmes états principaux : PAUSE et GAME).

Faire un jeu réutilisable :

Solutions :

Nous avons décidé d’utiliser des valeurs aléatoires et de programmer plusieurs chemins possibles en fonctions de ces valeurs pour que le jeu présente différents cas et qu’ainsi les parties ne soient pas répétitives. Ces différents chemins se feront directement à l’intérieur du module comme pour le morse ou au travers du numéro de série. Les chemins changent à chaque redémarrage de la carte pour proposer des parties différentes.

Mise en œuvre :

Nous avons utilisé la fonction random(min, max) pour générer des variables aléatoires. Il est à noter que la valeur minimale est incluse et que la valeur maximale est exclue, c’est pourquoi dans le module morse pour neuf mots nous avons pris la valeur alea = random(1,10).

La fonction random ne génère qu’une valeur aléatoire par téléversement, et non pas à chaque redémarrage de la carte. Nous avons donc rajouté la fonction randomSeed(analogRead(0)) qui lit une grandeur physique sur la sortie 0 qui n’est branchée à rien. Cette fonction permet de générer une valeur aléatoire différente à chaque mise sous tension de la carte.
Outils informatiques utilisés :

Nous avons utilisé le site d’échange de données GitHub afin de réunir les programmes et autres fichiers dans un dossier en ligne. Cela permet le partage des programmes et d’autres fichiers afin de les ouvrir sur n’importe quel ordinateur ayant les droits d’accès au projet. Notre projet sur Github :

https://github.com/trickart73/tipe_ktane/tree/master/bomb_defusal_game_v1

Le logiciel Fritzing a été utilisé pour réaliser les schémas du projet, ce logiciel permet également de simuler un projet et de créer les plans en circuit imprimé. Un schéma du circuit est essentiel pour pouvoir communiquer aux autres comment comprendre et réaliser un certain programme.

Nous avons aussi utilisé l’hébergeur de vidéos YouTube pour partager les vidéos de test.

Enfin nous avons évidemment utilisé Arduino pour la programmation du projet.

## III. Exploitation

Nous avons réalisé plus d’une vingtaine de tests avec des binômes différents. Il a fallu au début trouver le juste milieu au niveau de la difficulté et corriger les bogues rencontrés.


Figure 13 : Compte rendu des premières parties jouées

Nous voyons bien qu’au fur et à mesure des parties, les joueurs progressent.

Toutefois, les joueurs ayant testé le jeu ont été satisfaits et ont ressenti la frustration de la défaite des premières parties, leur donnant envie de rejouer.

Il est aussi important de noter que depuis ces 10 premières tentatives – où de nombreuses modifications ont été apportées au projet – aucun bogue (venant du programme ou de la conception des manuels) n’a été constaté. En effet, sur les 20 tentatives suivantes, le seul problème que nous ayons eu est un débranchement de fils (dû aux grands nombres de connexions).


Nous avons filmé le premier essai de M. Lanoix devant la bombe (disponible ici : https://www.youtube.com/watch?v=MbPvuHy70Hc&feature=youtu.be )

Figure 14 : Modifications apportées suites aux tests

## Conclusion :

Le cahier des charges du projet a en grande partie été rempli. Le jeu est désormais opérationnel.

Les cartes Arduino regorgent de possibilités et sont donc un bon support pour ce projet. En plus d’avoir une grande communauté, les accessoires électroniques sont peu chers et permettent de réaliser des maquettes facilement. Les cartes Arduino ont une grande capacité de calcul et de stockage étant donné que le code ne prend que très peu d’espace. Le programme que nous avons conçu n’occupe que 7% de la mémoire de la carte et permet donc un large développement du projet ultérieurement.

Maintenant, que peut devenir le projet ? Aujourd’hui, nous avons un jeu fonctionnel, comprenant 2 modules. Le jeu est grandement réutilisable avant de devenir facile. De plus, nous avons réalisé l’ensemble des modules selon la même architecture, en utilisant des classes. Sans rentrer dans les détails de conception, cela nous a permis d’obtenir un fichier « main » court et propre, idéal de tout programme. Les autres modules sont réalisés dans des fichiers à part (les « headers », avec pour extension « .h »).

Nous pouvons donc rajouter facilement des modules, à l’unique condition qu’ils ne soient pas bloquants !
Dans la conception en elle-même, Arduino reste un prototypage, avec des plaques d’essais. Nous pourrions facilement envisager de remplacer chaque module par un circuit imprimé, qui peut facilement se rajouter au jeu. Nous pourrions aussi rajouter une boîte plus adaptée, ou encore une batterie externe. Adapter le niveau de difficulté pourrait s’envisager, car nous avons remarqué durant les phases tests que la difficulté n’était pas ressentie de la même manière pour un étudiant en sciences qu’un étudiant en lettres (des calculs parfois conséquents peuvent être effectués).

Enfin, si nous décidons d’améliorer ce TIPE par la suite, nous pourrions aussi le porter sur Arduino UNO (avec l’aide d’un 74HC595, permettant de démultiplier le nombre de sorties/entrées sur l’Arduino). Techniquement parlant, l’Arduino UNO serait largement capable de recevoir et d’exécuter un tel programme. L’ultime étape serait d’utiliser un microcontrôleur (chipset) : l’Arduino ne deviendrait alors utile que pour téléverser le programme (interface chipset / ordinateur).
Remerciements

Nous remercions bien évidemment nos 2 professeurs, M. Lanoix et M. Delegue, qui nous ont guidé tout du long de ce projet. Un grand merci à Henri Rebecq, sans qui nous n’aurions pu réaliser ce projet tant son aide a été précieuse. Merci pour ses connaissances transmises, tant la logique et le raisonnement de construction d’un programme complexe, que des outils techniques comme les classes. Un merci aux parents (qui ont toujours été les premiers testeurs de versions pas toujours très abouties) et à tous ceux qui ont pu tester le jeu : leurs retours sont indispensables à l’amélioration du prototype.

## Bibliographie

- CFaury, « Le bouton poussoir », http://arduino.blaisepascal.fr/index.php/2017/11/30/le-bouton-poussoir/,02/18
- WMLogistic, « Code Morse avec une Led », https://forum.arduino.cc/index.php?topic=492308.0, 12/17
- TamiaLab, « Faire plusieurs choses à la fois avec une carte Arduino », https://www.carnetdumaker.net/articles/faire-plusieurs-choses-la-fois-avec-une-carte-arduino/, (https://www.carnetdumaker.net/articles/faire-plusieurs-choses-la-fois-avec-une-carte-arduino/) 03/18
- David LeGall, « Un minuteur à base d'Arduino », http://wikifab.org/wiki/Timer_:_Un_minuteur_%C3%A0_base_d%27Arduino,11/17
- Coding Badly, « The reliable but not very sexy way to seed random », http://forum.arduino.cc/index.php/topic,66206.0.html, 01/18
- Rob Faludi, « Buzzer Arduino Example Code », https://www.faludi.com/2007/04/23/buzzer-arduino-example-code/, 12/17
- Dxinteractive, « AnalogMultiButton », https://github.com/dxinteractive/AnalogMultiButton, 01/18

## Annexes

Annexe 1


Figure 15 : Diagramme d'états Timer

Figure 16: Planning (GANTT)

Annexe 2 :


Annexe 3 :

A l’heure actuelle, un seul duo à réussi à désamorcer la bombe en 5 minutes dans les conditions suivantes :

- Pas de triche
- Aucune aide des créateurs du jeu

## Clémence Potin & Antoine Vermorel

## (temps restant : 52 secondes)


Annexe 4 :

Figure 17 : Photo jeu dans son ensemble

Figure 18 : Photo Keyboard Module


Figure 19 : Photo Morse Module

Figure 20 : Photo Timer

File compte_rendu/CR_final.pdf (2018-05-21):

# 2017-2018 Rapport de TIPE NAHMIAZ Thomas, REBECQ Victor

PTSI 1 ECAM LYON

Est-il possible de faire un jeu sous Arduino ?

TIPE 2017-2018

## Table des matières

## Résumé :

Le projet proposé est un jeu physique sur Arduino. Le principe est de désamorcer une bombe, en équipe de deux joueurs ou plus. Deux équipes coopéreront lors du jeu :

- Le démineur : il peut voir la bombe, interagir avec elle mais ne connaît pas le procédé pour désamorcer la bombe.
- Les experts : ils possèdent un manuel qui permettra de résoudre les énigmes, mais ne peuvent pas interagir physiquement ou voir la bombe.

Ce jeu est donc purement coopératif, et la communication est primordiale. Les différents mini-jeux doivent être résolus dans un ordre quelconque mais dans un temps imparti de 5 minutes. Au-delà de ce temps ou si les joueurs font plus de 2 fautes, la bombe explosera.

## Introduction :

Premièrement nous aborderons la mise en place des idées à propos du projet, ses premières maquettes physiques ainsi que les exigences du projet. Puis, nous montrerons comment nous avons procédé pour obtenir plusieurs mini-jeux, jouables en même temps sur Arduino. Enfin, nous réaliserons un ensemble de tests, et nous évaluerons comment le projet pourra désormais évoluer.

## I. Mise en place :

Naissance du projet

Dès fin septembre, nous avions trouvé notre projet de TIPE : nous voulions tous deux faire un jeu, jouable physiquement (avec des boutons, LEDs, …). Après réflexion, et après avoir joué à la version ordinateur de Keep Talking and Nobody Explodes, (http://www.keeptalkinggame.com/) nous avons été convaincus que c’est ce jeu que nous voulions adapter physiquement.

Le principe du jeu est simple : 2 joueurs sont en équipe, et doivent désamorcer une bombe, composée d’énigmes. Un joueur voit la bombe, peut interagir avec elle mais ne connaît pas la solution aux énigmes (appelés « Modules » par la suite). L’autre joueur possède le manuel avec la procédure permettant de désamorcer chaque module, mais ne peut ni voir, ni toucher la bombe. C’est ce mélange de jeu coopératif, mêlant tensions et incompréhensions, qui nous a montré le potentiel que pouvait avoir ce concept.

Première maquette

Il fallait désormais prouver que ce concept était réalisable. Après une première explication orale, nous nous sommes heurtés à un avis plutôt mitigé. En effet, le concept est peut-être facile à comprendre mais il était difficile de voir si cette idée pouvait devenir un « jeu », et non rester une banale résolution d’énigme à 2.

Nous avons donc réalisé une maquette en carton de la bombe. Nous avons conçu 4 premiers modules (respectivement le module « Bouton », « Morse », « Accéléromètre » et « Films »). Un chemin précis (et unique, le jeu était difficilement rejouable) avait été déterminé. Pendant que l’un de nous deux faisait tourner les disques en carton attachés avec des attaches parisiennes, l’autre vérifiait que les modules étaient correctement réalisés, indiquait le temps restant, comptait les erreurs, … Nous nous sommes rendu compte que la difficulté de ce sujet allait être de pouvoir rendre notre programme « multi-tâches ».

Avec cette maquette, nous avons effectué une dizaine d’expérimentations et tiré plusieurs enseignements :

- Premièrement, le jeu n’avait un intérêt que s’il y avait une certaine pression, ajoutée par la limite de temps. Sans elle, le jeu aurait été dénué d’intérêt.
- Ensuite, malgré les défauts apparents d’un tel système, ainsi que la grossièreté de la maquette, chaque groupe de personnes testé (avec une limite de temps donc) eut un certain plaisir, une certaine envie de recommencer et de réussir. Cette maquette a d’ailleurs plutôt convaincu M.Delegue (qui faisait équipe avec M. Prachay).

Alors, confiants sur l’avenir du projet, nous nous sommes lancés dans la réalisation du programme.


Figure 1 : Photo de la maquette de la bombe sur une boite en carton

Lancement du projet, mise en place des exigences

En se basant sur nos idées nous avons conçu le cahier des charges suivant que nous avons suivi tout au long de l’année :

Exigences :

Concevoir un jeu : Priorité aux interactions entre les joueurs. Utiliser le minimum d’entrées/sorties.

Gérer plusieurs modules en même temps.
Pouvoir émuler des sons.
Avoir un programme propre et compréhensible

Pouvoir s’échanger des données facilement pendant le projet (entre concepteurs du projet). Avoir un manuel intuitif.

Réaliser un jeu rejouable.
Pouvoir ajouter d’autres modules facilement.

Utiliser un accéléromètre pour apporter une vraie dimension physique au jeu.

Nous avons également mis en place un planning en début de projet afin de mieux nous organiser. Voir l’annexe 2 pour voir la représentation du planning sous forme de diagramme de GANTT.

## II. Conception :

Création des modules :

Sans entrer dans une description fastidieuse du mini-jeu et/ou du programme, nous allons brièvement expliquer le principe de chaque module puis expliquer les principaux points de leur réalisation.
Module Keyboard

Figure 2 : Schéma du module Keyboard


Principe : Le démineur doit jouer une séquence précise composée de 9 notes. Les deux paramètres à prendre en compte sont :

- Le positionnement du « DO », qui peut changer de place parmi les 5 boutons. Cette position est déterminée grâce à un code.
- La séquence à jouer, qui varie selon les couleurs des LEDs allumées.

Deux principes assez fondamentaux sont intéressants à détailler ici :

- Emuler un son sous Arduino

Etant sur Arduino DUE (car plus grand nombre d’entrées/sorties) la fonction tone, fonctionnant sous Arduino UNO, n’est pas implémentée sur la version DUE.

Nous avons donc dû chercher une fonction nous permettant d’émuler un son.


Figure 3 : Comparaison des caractéristiques entre Arduino UNO et DUE


Figure 4: principe de la programmation du timer

Au-delà de trouver un programme qui fonctionne directement, il est intéressant de comprendre son fonctionnement.

3 attributs sont nécessaires pour cette fonction :

- La sortie du buzzer (buzzer actif, insérer une photo)
- La fréquence jouée (440 Hz pour un LA par exemple)
- La longueur de la note jouée

- Ce programme simule en réalité un signal carré (proche du signal sinusoidal désiré).
- Dans un premier temps, le programme calcule
la durée d’une période du signal carré
(delayValue).

Figure 5 : Signal carré

- Puis est calculé le nombre de cycles (numCycles) qui vont être nécessaires pour jouer le signal carré.
- Le « temps courant », juste avant de rentrer dans la boucle qui va émuler le signal carré, est noté start_Micros_buzz.
- Enfin, on entre dans une boucle qui passe dans l’état « Allumé » dèsl’entrée dans cette boucle. Le temps courant est à chaque fois actualisé dans la variable currentMicros_buzz.
- Quand le buzzer aura été allumé plus de temps qu’une période (currentMicros_buzz -start_Micros_buzz >= delayValue), il ne jouera plus de son. A ce moment, la variable start_Micros_buzz est réinitialisée.
- Cette boucle tournera autant de fois que nécessaire, c’est-à-dire autant de fois que numCycles.
- Boutons branchés en série

Une de nos contraintes était d’utiliser le moins d’entrées/sorties possible. Ayant beaucoup de composants à brancher, nous ne pouvions pas utiliser 5 sorties uniquement pour les boutons. Nous avons donc utilisé une des sorties analogiques de l’Arduino, puis branché en série les 5 boutons.

[Sortie 3.3V]
V
[2.2K résistance]
V
[Sortie analogique] --> Bouton 1 --> GND |
V
[1K résistance]
+--> Bouton 2 --> GND
V
[1K résistance]
+--> Bouton 3 --> GND
V
[1K résistance]
+--> Bouton 4 --> GND
V
[1K résistance]
+--> Bouton 5 --> GND
Figure 6 : Diagramme d'utilisation de la librairie AnalogMultiButton (source : gitHub librairie AnalogMultiButton)

Arduino attribue une valeur analogique aux boutons branchés en série entre 0 et 1023. Après quelques tests, on peut savoir quel bouton correspond à quelle valeur. La librairie AnalogMultiButton nous permet alors d’associer ces valeurs à chaque bouton.

Figure 7 : Déclaration des boutons du module « piano »

Module Timer :

Pour ce module, nous avons utilisé un afficheur 7 segments


Figure 8 : Principes de la programmation du timer

Dès que la bombe est lancée, le temps courant est sauvegardé dans la variable time_timer_launched.
Ainsi le temps à partir duquel la bombe a été lancée est calculé dans la variable time_elapsed_since_launched_sec.
On limite le temps d’écoulement du timer avec la variable préalablement définie time_max_bomb. Si time_elapsed_since_launched_sec > time_max_bomb, la bombe explose.

Enfin, l’afficheur 7 segments est rafraîchit et affiche continuellement le temps restant. La fonction resting_time permet de séparer les minutes et les secondes, pour afficher ces 2 éléments distinctement sur l’afficheur.
Module Morse :


Principe : Le joueur devant la bombe doit communiquer des signaux lumineux qu’il voit en morse afin que l’autre joueur déchiffre le bon mot parmi les neuf possibles.

Les mots sont directement convertis dans le programme afin de pouvoir changer facilement de mot sans erreurs. La fonction ToUpperCase transcrit les mots en majuscules pour avoir moins de lettres à coder, ensuite la fonction replace change toutes les lettres en suites de « . » et « - » selon le langage morse français. Il ne reste plus qu’à traduire les mots en signaux lumineux grâce à, entre autres, la fonction millis détaillée plus loin.

Nous avons utilisé la commande switch case pour choisir le mot en fonction de la valeur apportée par la commande Randomseed : l’avantage de cette commande par rapport à un if ... else est de raccourcir et clarifier nettement la syntaxe.

- Rebond du bouton :

L’appui sur un bouton poussoir peut ne pas transmettre qu’un seul contact mais plusieurs, dépendant de la qualité du bouton.


Figure 10: Schéma du signal émis par le rebond d'un bouton

Il y a deux façons de résoudre ce problème :

Figure 9 : Schéma du module Morse

- Utiliser un condensateur en parallèle pour adoucir le passage transitoire
- Attendre logiciellement un court instant (250 millisecondes) avant le décompte d’un autre appui sur le bouton pour être sûr de ne pas prendre en compte les rebonds.

C’est la deuxième solution qui a été choisie.
Module Accéléromètre

Il était prévu mais n’a pas été intégré dans le projet, faute de temps. Le joueur devait bouger un cube en fonction des indications de l’autre joueur. Ce module aurait rajouté une véritable dimension physique au jeu par rapport à un jeu virtuel. L’intention initiale était de faire des translations du cube dans l’espace. Or l’accéléromètre ne relève que l’accélération et l’orientation dans l’espace. Il n’était pas possible de relever avec précision les mouvements effectués. Nous avions donc adapté le manuel du démineur afin que le joueur doive effectuer des rotations du cube ce que l’accéléromètre permettait de faire avec plus de précision.

Une bibliothèque Arduino est dédiée à l’accéléromètre. Après avoir inclus la bibliothèque et initialisé l’accéléromètre il suffit de relever les valeurs relevées par celui-ci. Le joueur aurait dû mettre le cube dans la position indiquée par le manuel et appuyer sur un bouton pour relever la valeur des positions selon les axes X, Y et Z.

Gérer plusieurs modules en même temps :

Voici la partie la plus compliquée que nous ayons eu à réaliser.

La fonction delay est une fonction bloquante qui ne permet pas d’effectuer plusieurs tâches en parallèle. Ainsi, à chaque émulation de son le programme se gelait entièrement (l’afficheur 7 segments était principalement impacté). Nous avons donc opté pour l’utilisation de la fonction millis qui gère le temps sans être une fonction bloquante.

Pour expliquer ce concept, voici un programme non bloquant :


Figure 11 : Programme de deux Leds clignotant de manière désynchronisée

Ici, les 2 LEDs clignotent de manière complètement indépendante. Avec la fonction delay, il serait impossible de réaliser un tel programme.

Pour réaliser cela, nous avons contacté Henri Rebecq, frère de Victor, thésard à l’ETH/Université de Zürich. (https://www.ethz.ch/en.html) Nous n’avions aucune idée de comment réaliser cet assemblage de tousles modules, autant logiquement que techniquement (le langage Arduino étant proche du C, langage que nous ne connaissons pas bien).

Pour utiliser cette fonction millis, le programme a donc besoin de savoir – à chaque instant – dans quel état il se situe.

Pour cela, Henri nous a conseillé de réaliser une machine à état. Nous allons ici voir un exemple sur le module « Piano », sachant que les autres modules ont été réalisé d’une manière similaire (par souci de cohérence du programme).


Figure 12 : Diagramme d'états du module Keyboard

Selon le diagramme ci-dessus, nous avions donc défini plusieurs états :

- PAUSE : état initial du module. Lorsque la fonction reset est appelé (par l’appui d’un bouton par exemple), l’état passe à GAME.
- GAME : état principal, où l’appui sur un bouton est détecté. Plusieurs sous-états se suivent :
- NOTE_PLAYING : suit directement l’état GAME ; permet de jouer directement la note correspondant au bouton venant d’être appuyé
- CHECK_INPUT_VALUE : traite l’entrée du bouton (entrée correcte ou fausse).
- PLAY_FEEDBACK_CORRECT : allume une LED verte.
- PLAY_FEEDBACK_WRONG : allume une LED rouge et recommence le code à zéro.
- CODE_FOUND : le jeu revient à son état initial (PAUSE)

Le même principe a été appliqué pour le module « Morse ou « Timer ». (Voir annexe 2).

La fonction attachInterrupt permet d’arriver au même résultat. A chaque appui sur un bouton celle-ci effectue une tâche en priorité sur les autres. Cette fonction n’est cependant pas durable sur des programmes longs. Elle ne peut pas être utilisée un grand nombre de fois car appelée, elle devient totalement prioritaire sur le reste du programme.

Henri nous a aussi conseillé d’améliorer la lisibilité de notre programme. Pour cela, nous avons mis nos variables dans la même casse : en anglais, sans majuscule, avec un underscore. Nous avons aussi réalisé nos modules dans la même idée (machines à états appelant les mêmes états principaux : PAUSE et GAME).

Faire un jeu réutilisable :

Solutions :

Nous avons décidé d’utiliser des valeurs aléatoires et de programmer plusieurs chemins possibles en fonctions de ces valeurs pour que le jeu présente différents cas et qu’ainsi les parties ne soient pas répétitives. Ces différents chemins se feront directement à l’intérieur du module comme pour le morse ou au travers du numéro de série. Les chemins changent à chaque redémarrage de la carte pour proposer des parties différentes.

Mise en œuvre :

Nous avons utilisé la fonction random(min, max) pour générer des variables aléatoires. Il est à noter que la valeur minimale est incluse et que la valeur maximale est exclue, c’est pourquoi dans le module morse pour neuf mots nous avons pris la valeur alea = random(1,10).

La fonction random ne génère qu’une valeur aléatoire par téléversement, et non pas à chaque redémarrage de la carte. Nous avons donc rajouté la fonction randomSeed(analogRead(0)) qui lit une grandeur physique sur la sortie 0 qui n’est branchée à rien. Cette fonction permet de générer une valeur aléatoire différente à chaque mise sous tension de la carte.
Outils informatiques utilisés :

Nous avons utilisé le site d’échange de données GitHub afin de réunir les programmes et autres fichiers dans un dossier en ligne. Cela permet le partage des programmes et d’autres fichiers afin de les ouvrir sur n’importe quel ordinateur ayant les droits d’accès au projet. Notre projet sur Github :

https://github.com/trickart73/tipe_ktane/tree/master/bomb_defusal_game_v1

Le logiciel Fritzing a été utilisé pour réaliser les schémas du projet, ce logiciel permet également de simuler un projet et de créer les plans en circuit imprimé. Un schéma du circuit est essentiel pour pouvoir communiquer aux autres comment comprendre et réaliser un certain programme.

Nous avons aussi utilisé l’hébergeur de vidéos YouTube pour partager les vidéos de test.

Enfin nous avons évidemment utilisé Arduino pour la programmation du projet

## III. Exploitation

Nous avons réalisé plus d’une vingtaine de tests avec des binômes différents. Il a fallu au début trouver le juste milieu au niveau de la difficulté et corriger les bogues rencontrés.


Figure 13 : Compte rendu des premières parties jouées

Nous voyons bien qu’au fur et à mesure des parties, les joueurs progressent.

Toutefois, les joueurs ayant testé le jeu ont été satisfaits et ont ressenti la frustration de la défaite des premières parties, leur donnant envie de rejouer.

Il est aussi important de noter que depuis ces 10 premières tentatives – où de nombreuses modifications ont été apportées au projet – aucun bogue (venant du programme ou de la conception des manuels) n’a été constaté. En effet, sur les 20 tentatives suivantes, le seul problème que nous ayons eu est un débranchement de fils (dû aux grands nombres de connexions).


Nous avons filmé le premier essai de M. Lanoix devant la bombe (disponible ici : https://www.youtube.com/watch?v=MbPvuHy70Hc&feature=youtu.be )

Figure 14 : Modifications apportées suites aux tests

## Conclusion :

Le cahier des charges du projet a en grande partie été rempli. Le jeu est désormais opérationnel.

Les cartes Arduino regorgent de possibilités et sont donc un bon support pour ce projet. En plus d’avoir une grande communauté, les accessoires électroniques sont peu chers et permettent de réaliser des maquettes facilement. Les cartes Arduino ont une grande capacité de calcul et de stockage étant donné que le code ne prend que très peu d’espace. Le programme que nous avons conçu n’occupe que 7% de la mémoire de la carte et permet donc un large développement du projet ultérieurement.

Maintenant, que peut devenir le projet ? Aujourd’hui, nous avons un jeu fonctionnel, comprenant 2 modules. Le jeu est grandement réutilisable avant de devenir facile. De plus, nous avons réalisé l’ensemble des modules selon la même architecture, en utilisant des classes. Sans rentrer dans les détails de conception, cela nous a permis d’obtenir un fichier « main » court et propre, idéal de tout programme. Les autres modules sont réalisés dans des fichiers à part (les « headers », avec pour extension « .h »).

Nous pouvons donc rajouter facilement des modules, à l’unique condition qu’ils ne soient pas bloquants !
Dans la conception en elle-même, Arduino reste un prototypage, avec des plaques d’essais. Nous pourrions facilement envisager de remplacer chaque module par un circuit imprimé, qui peut facilement se rajouter au jeu. Nous pourrions aussi rajouter une boîte plus adaptée, ou encore une batterie externe. Adapter le niveau de difficulté pourrait s’envisager, car nous avons remarqué durant les phases tests que la difficulté n’était pas ressentie de la même manière pour un étudiant en sciences qu’un étudiant en lettres (des calculs parfois conséquents peuvent être effectués).

Enfin, si nous décidons d’améliorer ce TIPE par la suite, nous pourrions aussi le porter sur Arduino UNO (avec l’aide d’un 74HC595, permettant de démultiplier le nombre de sorties/entrées sur l’Arduino). Techniquement parlant, l’Arduino UNO serait largement capable de recevoir et d’exécuter un tel programme. L’ultime étape serait d’utiliser un microcontrôleur (chipset) : l’Arduino ne deviendrait alors utile que pour téléverser le programme (interface chipset / ordinateur).
Remerciements

Nous remercions bien évidemment nos 2 professeurs, M. Lanoix et M. Delegue, qui nous ont guidé tout du long de ce projet. Un grand merci à Henri Rebecq, sans qui nous n’aurions pu réaliser ce projet tant son aide a été précieuse. Merci pour ses connaissances transmises, tant la logique et le raisonnement de construction d’un programme complexe, que des outils techniques comme les classes. Un merci aux parents (qui ont toujours été les premiers testeurs de versions pas toujours très abouties) et à tous ceux qui ont pu tester le jeu : leurs retours sont indispensables à l’amélioration du prototype.

## Bibliographie

- CFaury, « Le bouton poussoir », http://arduino.blaisepascal.fr/index.php/2017/11/30/le-bouton-poussoir/,02/18
- WMLogistic, « Code Morse avec une Led », https://forum.arduino.cc/index.php?topic=492308.0, 12/17
- TamiaLab, « Faire plusieurs choses à la fois avec une carte Arduino », https://www.carnetdumaker.net/articles/faire-plusieurs-choses-la-fois-avec-une-carte-arduino/, (https://www.carnetdumaker.net/articles/faire-plusieurs-choses-la-fois-avec-une-carte-arduino/) 03/18
- David LeGall, « Un minuteur à base d'Arduino », http://wikifab.org/wiki/Timer_:_Un_minuteur_%C3%A0_base_d%27Arduino,11/17
- Coding Badly, « The reliable but not very sexy way to seed random », http://forum.arduino.cc/index.php/topic,66206.0.html, 01/18
- Rob Faludi, « Buzzer Arduino Example Code », https://www.faludi.com/2007/04/23/buzzer-arduino-example-code/, 12/17
- Dxinteractive, « AnalogMultiButton », https://github.com/dxinteractive/AnalogMultiButton, 01/18

## Annexes

Annexe 1


Figure 15 : Diagramme d'états Timer

Figure 16: Planning (GANTT)

Annexe 2 :


Annexe 3 :

A l’heure actuelle, un seul duo à réussi à désamorcer la bombe en 5 minutes dans les conditions suivantes :

- Pas de triche
- Aucune aide des créateurs du jeu

## Clémence Potin & Antoine Vermorel

## (temps restant : 52 secondes)


Annexe 4 :

Figure 17 : Photo jeu dans son ensemble

Figure 18 : Photo Keyboard Module


Figure 19 : Photo Morse Module

Figure 20 : Photo Timer

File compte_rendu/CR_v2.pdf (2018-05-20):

# 2017-2018 Rapport de TIPE NAHMIAZ Thomas REBECQ Victor

PTSI 1

Est-il possible de faire un jeu sous Arduino ?

TIPE 2017-2018

## Table des matières

## Résumé :

Le projet proposé est un jeu physique sur Arduino. Le principe est de désamorcer une bombe, en équipe de deux joueurs ou plus. Deux équipes coopéreront lors du jeu :

Le démineur : il peut voir la bombe, interagir avec elle mais ne connait pas le procédé pour désamorcer la bombe.

Les experts : ils possèdent un manuel qui permettra de résoudre les énigmes, mais ne peuvent pas interagir physiquement ou voir la bombe.

Ce jeu est donc purement coopératif, et la communication est primordiale. Les différents mini-jeux doivent être résolus dans un ordre quelconque mais dans un temps imparti de 5 minutes. Au-delà de ce temps ou si les joueurs font plus de 2 fautes, la bombe explosera.

## Introduction :

Premièrement nous aborderons la mise en place des idées à propos du projet, ses premières maquettes physiques ainsi que les exigences du projet. Puis, nous montrerons comment nous avons procédé pour obtenir plusieurs mini-jeux, jouable en même temps sur Arduino. Enfin, nous réaliserons un ensemble de tests, et nous évaluerons comment le projet pourra désormais évoluer.

## I. Mise en place :

Naissance du projet

Dès fin septembre, nous avions trouvé notre projet de TIPE : nous voulions tous les deux faire un jeu, jouable physiquement (avec des boutons, LEDs,…). Après réflexion, et après avoir joué à la version ordinateur de Keep Talking and Nobody Explodes, (http://www.keeptalkinggame.com/) nous avons été convaincus que c’est ce jeu que nous voulions adapter physiquement.

Le principe du jeu est simple : 2 joueurs sont en équipe, et doivent désamorcer une bombe, composée d’énigmes. Un joueur voit la bombe, peut interagir avec elle mais ne connait pas la solution aux énigmes (appelés « Modules » dans la suite). L’autre joueur possède le manuel avec la procédure permettant de désamorcer chaque module, mais ne peut ni voir, ni toucher la bombe. C’est ce mélange de jeu coopératif, mêlant tensions et incompréhensions, qui nous a montré le potentiel que pouvait avoir ce concept.

Première maquette

Il | fallait | désormais | prouver | que | ce | concept | était | viable | et | réalisable.
Après une première explication orale, nous nous sommes heurtés à un avis plutôt mitigé. En effet, le concept est peut-être facile à comprendre mais il était difficile de voir si cette idée pouvait devenir un « jeu », et non rester une banale résolution d’énigme à 2.

Nous avons donc réalisé une maquette en carton de la bombe. Nous avons conçu 4 premiers modules (respectivement le module « Bouton », « Morse », « Accéléromètre » et « Films »). Un chemin précis (et unique, le jeu était difficilement rejouable) avait été déterminé. Pendant que l’un de nous deux faisait tourner les disques en carton attachés avec des attaches parisiennes, l’autre vérifiait que les modules étaient correctement réalisés, indiquait le temps restant, comptait les erreurs, ... C’est la première prise de conscience que le point important de ce sujet allait être de pouvoir rendre notre programme « multi-tâche ».

Avec cette maquette, nous avons effectué une dizaine d’expérimentations et tiré plusieurs enseignements :

- Premièrement, le jeu n’avait un intérêt que s’il y avait une certaine pression, ajoutée par la limite de temps. Sans elle, le jeu aurait été dénué d’intérêt.
- Ensuite, malgré les défauts apparents d’un tel système, ainsi que la grossièreté de la maquette, chaque groupe de personne testé (avec une limite de temps donc) eu un certain plaisir, une certaine envie de recommencer et de réussir. Cette maquette a d’ailleurs plutôt convaincu M.Delegue (qui faisait équipe avec M. Prachay).

Alors, confiants sur l’avenir du projet, nous nous sommes lancés dans la réalisation du programme.


Figure 1 : Photo de la maquette de la bombe sur une boite en carton

Lancement du projet, mise en place des exigences

En se basant sur nos idées nous avons conçu le cahier des charges suivant que nous avons suivit tout au long de l’année :

Exigences :

Faire un jeu : Priorité aux interactions entre les joueurs. Utiliser le minimum d’entrées/sorties.

Gérer plusieurs modules en même temps.
Pouvoir émuler des sons.
Avoir un programme propre.

Pouvoir s’échanger des données facilement pendant le projet (entre concepteurs du projet). Avoir un manuel propre et intuitif.

Faire un jeu réutilisable, rejouable.
Pouvoir ajouter d’autres modules facilement.

Utiliser un accéléromètre pour donner une vraie dimension physique au jeu.

Nous avons également mis en place un planning tout au long du projet afin de mieux nous organiser. Voir l’annexe 2 pour voir la représentation du planning sous forme de diagramme de GANTT.

## II. Conception :

Création des modules :

Sans entrer dans une description fastidieuse du mini-jeu et/ou du programme, nous allons brièvement expliquer le principe de chaque module puis expliquer les principaux points de leur réalisation.
Module Keyboard

Figure 2 : Schéma du module Keyboard


Principe : Le démineur doit jouer une séquence précise composée de 9 notes. Les 2 paramètres à prendre en compte sont :

- Le positionnement du « DO », qui peut changer de place parmi les 5 boutons. Cette position est déterminée grâce à un code.
- La séquence à jouer, qui varie selon les couleurs des LEDs allumées.

2 principes assez fondamentaux sont intéressants à détailler ici :

- Emuler un son sous Arduino

Etant sur Arduino DUE (car plus grand nombre d’entrées/sorties)la fonction tone, grandement utilisée sous Arduino UNO ne peut pas être utilisé.

Nous avons donc dû chercher une fonction nous permettant d’émuler un son.


Figure 3 : Comparaison des caractéristiques entre Arduino UNO et DUE


Figure 4: principe de la programmation du timer

Au-delà de trouver un programme qui fonctionne directement, il est intéressant de comprendre son fonctionnement.

3 attributs sont nécessaires pour cette fonction :

- La sortie du buzzer (buzzer actif, insérer une photo)
- La fréquence jouée (540 Hz pour un LA par exemple)
- La longueur de la note jouée

- Ce programme simule en réalité un signal carré (proche du signal sinusoidal désiré).
- Dans un premier temps, le programme calcule
la durée d’une période du signal carré
(delayValue).

Figure 5 : Signal carré

- Puis est calculé le nombre de cycles (numCycles) qui vont être nécessaire pour jouer le signal carré.
- Le « temps courant », juste avant de rentrer dans la boucle qui va émuler le signal carré, est noté start_Micros_buzz.
- Enfin, on entre dans une boucle qui passe dans l’état « Allumé » dèsl’entrée dans cette boucle. Le temps courant est à chaque fois actualisé dans la variable currentMicros_buzz.
- Quand le buzzer aura été allumé plus de temps qu’une période (currentMicros_buzz -start_Micros_buzz >= delayValue) , il ne jouera plus de son. A ce moment, la variable start_Micros_buzz est réinitialisé.
- Cette boucle tournera autant de fois que nécessaire, c’est-à-dire autant de fois que numCycles.
- Boutons branchés en série

Une de nos contraintes était d’utiliser le moins d’entrées/sorties possibles. Ayant beaucoup de composants à brancher, nous ne pouvions pas utiliser 5 sorties uniquement pour les boutons. Nous avons donc utilisé une des sorties analogiques de l’arduino, puis branché en série les 5 boutons.

[Sortie 3.3V]
V
[2.2K résistance]
V
[Sortie analogique] --> Bouton 1 --> GND |
V
[1K résistance]
+--> Bouton 2 --> GND
V
[1K résistance]
+--> Bouton 3 --> GND
V
[1K résistance]
+--> Bouton 4 --> GND
V
[1K résistance]
+--> Bouton 5 --> GND
Figure 6 : Diagramme d'utilisation d'Analog Multi Button (source : gitHub librairie AnalogMultiButton)

Arduino attribue une valeur analogique aux boutons branchés en série entre 0 et 1023. Après quelques tests, on peut savoir quel bouton correspond à quelle valeur. La librairie AnalogMultiButton nous permet alors d’associer ces valeurs à chaque bouton.

Figure 7 : Déclaration des boutons du module « piano »

Module Timer :

Pour ce module, nous avons utilisé un afficheur 7 segments


Figure 8 : Principes de la programmation du timer

Dès que la bombe est lancée, le temps courant est sauvegardé dans la variable time_timer_launched.
Ainsi | est | calculé | le | temps | depuis | lequel | la | bombe | a | été | lancée
(time_elapsed_since_launched_sec).
Avec une boucle Tant Que, on limite le temps d’écoulement du timer avec la variable préalablement définie time_max_bomb.

Enfin, l’afficheur 7 segment est rafraichi et affiche continuellement le temps restant. La fonction resting_time permet de séparer les minutes et les secondes, pour afficher ces 2 éléments distinctement sur l’afficheur.
Module Morse :


Principe: Le joueur devant la bombe doit communiquer des signaux lumineux qu’il voit en morse afin que l’autre joueur déchiffre le bon mot parmi les neufs possibles.

Les mots sont directement convertis dans le programme afin de pouvoir changer facilement de mot sans erreurs. La fonction ToUpperCase transcrit les mots en majuscules pour avoir moins de lettres à coder, ensuite la fonction replace change toutes les lettres en suites de « . » et « - » selon le langage morse français. Il ne reste plus qu’à traduire les mots en signaux lumineux grâce à, entre autres, la fonction millis détaillée plus loin.

Nous avons utilisé la commande switch case pour choisir le mot en fonction de la valeur apportée par la commande Randomseed : l’avantage de cette commande par rapport à un if .. else est de raccourcir et clarifier nettement la syntaxe.

Rebond du bouton :

L’appui sur un bouton poussoir peut ne pas transmettre qu’un seul contact mais plusieurs, dépendant de la qualité du bouton.


Figure 10: Schéma du signal émis par le rebond d'un bouton

Il y a deux façons de résoudre ce problème :

Figure 9 : Schéma du module Morse

Utiliser un condensateur en parallèle pour adoucir le passage transitoire ou attendre logiciellement un court instant (250 millisecondes) avant le décompte d’un autre appui sur le bouton pour être sûr de ne pas prendre en compte les rebonds. C’est la deuxième solution qui a été choisie.
Module Accéléromètre

Il était prévu mais n’a pas été intégré dans le projet, faute de temps. Le joueur devait bouger un cube en fonction des indications de l’autre joueur. Ce module aurait rajouté une véritable dimension physique au jeu par rapport à un jeu virtuel. L’intention initiale était de faire des translations du cube dans l’espace. Or l’accéléromètre ne relève que l’accélération et l’orientation dans l’espace. Il n’était pas possible de relever avec précision les mouvements effectués. Nous avions donc adapté le manuel du démineur afin que le joueur doive effectuer des rotations du cube ce que l’accéléromètre permettait de faire avec plus de précision.

Une bibliothèque Arduino est dédiée à l’accéléromètre. Après avoir inclus la bibliothèque et initialisé l’accéléromètre il suffit de relever les valeurs relevées par celui-ci. Le joueur aurait dû mettre le cube dans la position indiquée par le manuel et appuyer sur un bouton pour relever la valeur des positions selon les axes X, Y et Z.

Gérer plusieurs modules en même temps :

Voici la partie la plus compliquée que nous ayons eu à réaliser.

La fonction delay est une fonction bloquante qui ne permet pas d’effectuer plusieurs tâches en parallèle. Ainsi, à chaque émulation de son le programme se gelait entièrement (l’afficheur 7 segments était principalement impacté). Nous avons donc opté pour l’utilisation de la fonction millis qui gère le temps sans être une fonction bloquante selon le modèle :

Pour expliquer ce concept, voici un programme non bloquant :


Figure 11 : Programme de deux Leds clignotant de manière désynchronisée

Ici, les 2 LEDs clignotent de manière complètement indépendante. Avec la fonction delay, il serait impossible de réaliser un tel programme.

Pour réaliser cela, nous avons contacté Henri Rebecq, frère de Victor, ingénieur diplômé de l’école Paris Telecom et travaillant actuellement sur sa thèse à l’ETH de Zurich. Nous n’avions aucune idée de comment réaliser cet assemblage de tous les modules, autant logiquement que techniquement (le langage Arduino étant proche du C, langage que nous ne connaissons pas bien).

Pour utiliser cette fonction millis, le programme a donc besoin de savoir – à chaque instant – dans quel état il se situe.

Pour cela, Henri nous a conseillé de réaliser une machine à état. Nous allons ici voir un exemple sur le module « Piano », sachant que les autres modules ont été réalisé d’une manière similaire (par souci de cohérence du programme).


Figure 12 : Diagramme d'états du module Keyboard

Selon le diagramme ci-dessus, nous avions donc défini plusieurs états :

- PAUSE : état initial du module. Lorsque la fonction reset est appelé (par l’appui d’un bouton par exemple), l’état passe à GAME.
- GAME : état principal, où l’appui sur un bouton est détecté. Plusieurs sous-états se suivent :
- NOTE_PLAYING : suit directement l’état GAME ; permet de jouer directement la note correspondant au bouton venant d’être appuyé
- CHECK_INPUT_VALUE : traite l’entrée du bouton (entrée correcte ou fausse).
- PLAY_FEEDBACK_CORRECT : allume une LED verte.
- PLAY_FEEDBACK_WRONG : allume une LED rouge et recommence le code à zéro.
- CODE_FOUND : Le jeu revient à son état initial (PAUSE)

Le même principe a été appliqué pour le module « Morse ou « Timer ». (Voir annexe 2).

La fonction attachInterrupt permet d’arriver au même résultat. A chaque appui sur un bouton celle-ci effectue une tâche en priorité sur les autres. Cette fonction n’est cependant pas durable sur des programmes longs et ne peut pas être utilisée un grand nombre de fois en tant qu’une seule fonction ne peut être appelée dans le même temps.

Henri nous a aussi conseillé d’améliorer la lisibilité de notre programme. Pour cela, nous avons mis nos variables dans la même casse : en anglais, sans majuscule, avec un underscore. Nous avons aussi réalisé nos modules dans la même idée (machines à états appelant les mêmes états principaux : PAUSE et GAME).

Faire un jeu réutilisable :

Solutions :

Nous avons décidé d’utiliser des valeurs aléatoires et de programmer plusieurs chemins possibles en fonctions de ces valeurs pour que le jeu présente différents cas et qu’ainsi les parties ne soient pas répétitives. Ces différents chemins se feront directement à l’intérieur du module comme pour le morse ou au travers du numéro de série. Les chemins changent à chaque redémarrage de la carte pour proposer des parties différentes.

Mise en œuvre :

Nous avons utilisé la fonction random(min, max) pour générer des variables aléatoires. Il est à noter que la valeur minimale est incluse et que la valeur maximale est exclue, c’est pourquoi dans le module morse pour neuf mots nous avons pris la valeur alea = random(1,10).

La fonction random ne génère qu’une valeur aléatoire par téléversement, et non pas à chaque redémarrage de la carte. Nous avons donc rajouté la fonction randomSeed(analogRead(0)) qui lit une grandeur physique sur la sortie 0 qui n’est branchée à rien. Cette fonction permet de générer une valeur aléatoire différente à chaque mise sous tension de la carte.
Outils informatiques utilisés :

Nous avons utilisé le site d’échange de données GitHub afin de réunir les programmes et autres fichiers dans un dossier en ligne. Cela permet le partage des programmes et d’autres fichiers afin de les ouvrir sur n’importe quel ordinateur ayant les droits d’accès au projet. Notre projet sur Github :

https://github.com/trickart73/tipe_ktane/tree/master/bomb_defusal_game_v1

Le logiciel Fritzing a été utilisé pour réaliser les schémas du projet, ce logiciel permet également de simuler un projet et de créer les plans en circuit imprimé. Un schéma du circuit est essentiel pour pouvoir communiquer aux autres comment comprendre et réaliser un certain programme.

Nous avons aussi utilisé l’hébergeur de vidéos YouTube pour partager les vidéos de test.

Enfin nous avons évidemment utilisé Arduino pour la programmation du projet

## III. Exploitation

Nous avons réalisé plus d’une vingtaine de tests avec des binômes différents. Il a fallu au début trouver le juste milieu au niveau de la difficulté et corriger les bogues rencontrés.


Figure 13 : Compte rendu des premières parties jouées

Nous voyons bien qu’au fur et à mesure des parties, les joueurs progressent.

Toutefois, les joueurs ayant testé le jeu ont été satisfaits et ont ressenti la frustration de la défaite des premières parties, leur donnant envie de rejouer.

Il est aussi important de noter que depuis ces 10 premières tentatives – où de nombreuses modifications ont été apportées au projet – aucun bogue (venant du programme ou de la conception des manuels) n’a été constaté. En effet, sur les 20 tentatives suivantes, le seul problème que nous ayons eu est un débranchement de fils (dû aux grands nombres de connexions).

Nous avons filmé le premier essai de M. Lanoix devant


la | bombe | (disponible | ici :
https://www.youtube.com/watch?v=MbPvuHy70Hc&feature=youtu.be )

Figure 14 : Modifications apportées suites aux tests

## Conclusion :

Le cahier des charges du projet a en grande partie été rempli. Le jeu est désormais opérationnel.

Les cartes Arduino regorgent de possibilités et sont donc un bon support pour ce projet. En plus d’avoir une grande communauté, les accessoires électroniques sont peu chers et permettent de réaliser des maquettes facilement. Les cartes Arduino ont une grande capacité de calcul et de stockage étant donné que le code ne prend que très peu d’espace. Le programme que nous avons conçu n’occupe que 7% de la mémoire de la carte et permet donc un large développement du projet ultérieurement.

Pour finir, que peux devenir le projet ? Aujourd’hui, nous avons un jeu fonctionnel, comprenant 2 modules. Le jeu est grandement réutilisable avant de devenir facile. De plus, nous avons réalisé l’ensemble des modules selon la même architecture, en utilisant des classes. Sans rentrer dans les détails de conception, cela nous a permis d’obtenir un fichier « main » court et propre, idéal de tout programme. Les autres modules sont réalisés dans des fichiers à part (les « headers », avec pour extension « .h »).

Nous pouvons donc rajouter facilement des modules, à l’unique condition qu’ils ne soient pas bloquants !
Dans la conception en elle-même, Arduino reste un prototypage, avec des plaques d’essais. Nous pourrions facilement envisager de remplacer chaque module par un circuit imprimé, qui peut facilement se rajouter au jeu. Nous pourrions aussi rajouter une boîte plus adaptée, ou encore une batterie externe, ou un système de difficulté (Facile ou Difficile), car nous avons remarqué durant les phases tests que la difficulté n’était pas ressentie de la même manière pour un étudiant en sciences qu’un étudiant en lettres (des calculs parfois conséquents peuvent être effectués).

Enfin, si nous décidons d’améliorer ce TIPE par la suite, nous pourrions aussi le porter sur Arduino UNO (avec l’aide d’un 74HC595, permettant de démultiplier le nombre de sorties/entrées sur l’Arduino). Techniquement parlant, l’Arduino Uno serait largement
capable | de | recevoir | et | d’exécuter | un | tel | programme.
L’ultime étape serait d’utiliser un microcontrôleur (chipset) : l’Arduino ne deviendrait alors utile que pour téléverser le programme (interface chipset / ordinateur).
Remerciements

Nous remercions bien évidemment nos 2 professeurs, M. Lanoix et M. Delegue, qui nous ont guidé tout du long de ce projet. Un grand merci à Henri Rebecq, sans qui nous n’aurions pu réaliser ce projet tant son aide a été précieuse. Les connaissances qu’il nous as transmises -tant la logique et le raisonnement de construction d’un programme complexe, que des outils techniques comme les classes – nous seront certainement utile pour le reste de nos années de programmeur. Un merci aux parents (qui ont toujours été les premiers testeurs de versions pas toujours très abouties) et à tous ceux qui ont pu tester le jeu, leurs retours sont indispensables à l’amélioration du jeu.

## Bibliographie :

- CFaury, « Le bouton poussoir », http://arduino.blaisepascal.fr/index.php/2017/11/30/le-bouton-poussoir/,02/18
- WMLogistic, « Code Morse avec une Led », https://forum.arduino.cc/index.php?topic=492308.0, 12/17
- TamiaLab, « Faire plusieurs choses à la fois avec une carte Arduino », https://www.carnetdumaker.net/articles/faire-plusieurs-choses-la-fois-avec-une-carte-arduino/, (https://www.carnetdumaker.net/articles/faire-plusieurs-choses-la-fois-avec-une-carte-arduino/) 03/18
- David LeGall, « Un minuteur à base d'Arduino », http://wikifab.org/wiki/Timer_:_Un_minuteur_%C3%A0_base_d%27Arduino,11/17
- Coding Badly, « The reliable but not very sexy way to seed random », http://forum.arduino.cc/index.php/topic,66206.0.html, 01/18
- Rob Faludi, « Buzzer Arduino Example Code », https://www.faludi.com/2007/04/23/buzzer-arduino-example-code/, 12/17
- Dxinteractive, « AnalogMultiButton », https://github.com/dxinteractive/AnalogMultiButton, 01/18

## Annexes

Annexe 1


Figure 15 : Diagramme d'états Timer

Figure 16: Planning (GANTT)

Annexe 2 :


Annexe 3 :

A l’heure actuelle, un seul duo à réussi à désamorcer la bombe en 5 minutes dans les conditions suivantes :

- Pas de triche
- Aucune aide des créateurs du jeu


## Clémence Potin & Antoine Vermorel

## (temps restant : 52 secondes)


Annexe 4 :

Figure 17 : Photo jeu dans son ensemble

Figure 18 : Photo Keyboard Module


Figure 19 : Photo Morse Module

Figure 20 : Photo Timer

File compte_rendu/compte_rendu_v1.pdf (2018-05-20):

# 2017-2018 Rapport de TIPE NAHMIAZ Thomas REBECQ Victor

PTSI 1

Est-il possible de faire un jeu sous Arduino ?

TIPE 2017-2018

## Table des matières

## Résumé :

Le projet proposé est un jeu physique sur Arduino. Le principe est de désamorcer une bombe, en équipe de deux joueurs ou plus. Deux équipes coopéreront lors du jeu :

Le démineur : il peut voir la bombe, interagir avec elle mais ne connait pas le procédé pour désamorcer la bombe.

Les experts : ils possèdent un manuel qui permettra de résoudre les énigmes, mais ne peuvent pas interagir physiquement ou voir la bombe.

Ce jeu est donc purement coopératif, où la communication est primordiale. Les différents mini-jeux doivent être résolus dans un ordre quelconque mais un temps imparti de 5 minutes. Au-delà de ce temps ou si les joueurs font plus de 2 fautes, la bombe explosera.

## Introduction :

Premièrement nous aborderons la mise en place des idées à propos du projet, ses premières maquettes physiques ainsi que les exigences du projet. Puis, nous montrerons comment nous avons procédé pour obtenir plusieurs mini-jeux, jouable en même temps sur Arduino. Enfin, nous réaliserons un ensemble de tests, et nous évaluerons comment le projet pourra désormais évoluer.

## I. Mise en place :

Naissance du projet

Dès fin septembre, nous avions trouvé notre projet de TIPE : nous voulions tous les deux faire un jeu, jouable physiquement (avec des boutons, LEDs,…). Après réflexion, et après avoir joué à la version ordinateur de Keep Talking and Nobody Explodes, (http://www.keeptalkinggame.com/) nous avons été convaincus que c’est ce jeu que nous voulions adapter physiquement.

Le principe du jeu est simple : 2 joueurs sont en équipe, et doivent désamorcer une bombe, composée d’énigmes. Un joueur voit la bombe, peut interagir avec elle mais ne connait pas la solution aux énigmes (appelés « Modules » dans la suite). L’autre joueur possède le manuel avec la procédure permettant de désamorcer chaque module, mais ne peut ni voir, ni toucher la bombe. C’est ce mélange de jeu coopératif, mêlant tensions et incompréhension, qui nous a montré le potentiel que pouvait avoir ce concept.

Première maquette

Il | fallait | désormais | prouver | que | ce | concept | était | viable | et | réalisable.
Après une première explication orale, nous nous sommes heurtés à un avis plutôt mitigé. En effet, le concept est peut-être facile à comprendre mais il était dur de voir si cette idée pouvait devenir un « jeu », et non rester une banale résolution d’énigme à 2.

Nous avons donc réalisé une maquette en carton de la bombe. Nous avons conçu 4 premiers modules (respectivement le module « Bouton », « Morse », « Accéléromètre » et « Films »). Un chemin précis (et unique, le jeu était difficilement rejouable) avait été déterminé. Pendant que l’un de nous deux faisait tourner les disques en carton attachés avec des attaches parisiennes, l’autre vérifiait que les modules étaient correctement réalisés, indiquait le temps restant, comptait les erreurs, ... C’est la première prise de conscience que le point important de ce sujet allait être de pouvoir rendre notre programme « multi-tâche ».

Avec cette maquette, nous avons effectué une dizaine d’expérimentations et tiré plusieurs enseignements :

- Premièrement, le jeu n’avait un intérêt que s’il y avait une certaine pression, ajoutée par la limite de temps. Sans elle, le jeu aurait été dénué d’intérêt.
- Ensuite, malgré les défauts apparents d’un tel système, ainsi que la grossièreté de la maquette, chaque groupe de personne testé (avec une limite de temps donc) eu un certain plaisir, une certaine envie de recommencer et de réussir. Cette maquette a d’ailleurs plutôt convaincu M.Delegue (qui faisait équipe avec M. Prachay).

Alors, confiants sur l’avenir du projet, nous nous sommes lancés dans la réalisation du programme.


Figure 1 : Photo de la maquette de la bombe sur une boite en carton
Lancement du projet, mise en place des exigences

En se basant sur nos idées nous avons conçu le cahier des charges suivant que nous avons suivit tout au long de l’année :

Exigences :

Faire un jeu : Priorité aux interactions entre les joueurs. Utiliser le minimum d’entrées/sorties.

Gérer plusieurs modules en même temps.
Pouvoir émuler des sons.
Avoir un programme propre.

Pouvoir s’échanger des données facilement pendant le projet (entre concepteurs du projet). Avoir un manuel propre et intuitif.

Faire un jeu réutilisable, rejouable.
Pouvoir ajouter d’autres modules facilement.

Utiliser un accéléromètre pour donner une vraie dimension physique au jeu.

Nous avons également mis en place un planning tout au long du projet afin de mieux nous organiser. Voir l’annexe 2 pour voir la représentation du planning sous forme de diagramme de GANTT.

## II. Conception :

Création des modules :

Sans entrer dans une description fastidieuse du mini-jeu et/ou du programme, nous allons brièvement expliquer le principe de chaque module puis expliquer les principaux points de leur réalisation.
Module Keyboard

Figure 2 : Schéma du module Keyboard


Principe : Le démineur doit jouer une séquence précise composée de 9 notes. Les 2 paramètres à prendre en compte sont :

- Le positionnement du « DO », qui peut changer de place parmi les 5 boutons. Cette position est déterminée grâce à un code.
- La séquence à jouer, qui varie selon les couleurs des LEDs allumées.

2 principes assez fondamentaux sont intéressants à détailler ici :

- Emuler un son sous Arduino

Etant sur Arduino DUE (car plus grand nombre d’entrées/sorties)la fonction tone, grandement utilisée sous Arduino UNO ne peut pas être utilisé.

Nous avons donc dû chercher une fonction nous permettant d’émuler un son.


Figure 3 : Comparaison des caractéristiques entre Arduino UNO et DUE


Figure 4: principe de la programmation du timer

Au-delà de trouver un programme qui fonctionne directement, il est intéressant de comprendre son fonctionnement.

3 attributs sont nécessaires pour cette fonction :

- La sortie du buzzer (buzzer actif, insérer une photo)
- La fréquence jouée (540 Hz pour un LA par exemple)
- La longueur de la note jouée
- Ce programme simule en réalité un signal
carré (proche du signal sinusoidal désiré).
- Dans un premier temps, le programme calcule
la durée d’une période du signal carré
(delayValue).

Figure 5 : Signal carré

- Puis est calculé le nombre de cycles (numCycles) qui vont être nécessaire pour jouer le signal carré.
- Le « temps courant », juste avant de rentrer dans la boucle qui va émuler le signal carré, est noté start_Micros_buzz.
- Enfin, on entre dans une boucle qui passe dans l’état « Allumé » dèsl’entrée dans cette boucle. Le temps courant est à chaque fois actualisé dans la variable currentMicros_buzz.
- Quand le buzzer aura été allumé plus de temps qu’une période (currentMicros_buzz -start_Micros_buzz >= delayValue) , il ne jouera plus de son. A ce moment, la variable start_Micros_buzz est réinitialisé.
- Cette boucle tournera autant de fois que nécessaire, c’est-à-dire autant de fois que numCycles.

- Boutons branchés en série

Une de nos contraintes étaient d’utiliser le moins d’entrées/sorties possibles. Ayant beaucoup de composants à brancher, nous ne pouvions pas utiliser 5 sorties uniquement pour les boutons. Nous avons donc utilisé une des sorties analogiques de l’arduino, puis branché en série les 5 boutons.

[Sortie 3.3V]
V
[2.2K résistance]
V
[Sortie analogique] --> Bouton 1 --> GND |
V
[1K résistance]
+--> Bouton 2 --> GND
V
[1K résistance]
+--> Bouton 3 --> GND
V
[1K résistance]
+--> Bouton 4 --> GND
V
[1K résistance]
+--> Bouton 5 --> GND
Figure 6 : Diagramme d'utilisation d'Analog Multi Button (source : gitHub librairie AnalogMultiButton)

Arduino attribue une valeur analogique aux boutons branchés en série entre 0 et 1023. Après quelques tests, on peut savoir quel bouton correspond à quelle valeur. La librairie AnalogMultiButton nous permet alors d’associer ces valeurs à chaque bouton.

Figure 7 : Déclaration des boutons du module « piano »

Module Timer :

Pour ce module, nous avons utilisé un afficheur 7 segments


Figure 8 : Principes de la programmation du timer

Dès que la bombe est lancée, le temps courant est sauvegardé dans la variable time_timer_launched.
Ainsi | est | calculée | le | temps | depuis | lequel | la | bombe | a | été | lancée
(time_elapsed_since_launched_sec).
Avec une boucle Tant Que, on limite le temps d’écoulement du timer avec la variable préalablement définie time_max_bomb.

Enfin, l’afficheur 7 segment est rafraichi et affiche continuellement le temps restant. La fonction resting_time permet de séparer les minutes et les secondes, pour afficher ces 2 éléments distinctement sur l’afficheur.

Module Morse :

Principe: Le joueur devant la bombe doit communiquer des signaux qu’il voit en morse afin que l’autre joueur déchiffre le bon mot parmi neufs possibles.

Les mots sont directement convertis dans le programme afin de pouvoir changer facilement de mot sans erreurs. La fonction ToUpperCase transcrit les mots en majuscules pour avoir moins de lettres à coder, ensuite la fonction replace change toutes les lettres en suites de « . » et « - » selon le langage morse français. Il ne reste


plus qu’à traduire les mots en signaux lumineux grâce à, entre autres, la fonction millis détaillée plus loin.

Nous avons utilisé la commande switch case pour choisir le mot en fonction de la valeur apportée par la commande Randomseed : l’avantage de cette commande par rapport à un if .. else est de raccourcir et clarifier nettement la syntaxe.

Rebond du bouton :

L’appui sur un bouton poussoir peut ne pas transmettre qu’un seul contact mais plusieurs, dépendant de la qualité du bouton.


Figure 10: Schéma du signal émis par le rebond d'un bouton

Il y’a deux façons de résoudre ce problème :

Utiliser un condensateur en parallèle pour adoucir le passage transitoire ou attendre logiciellement un court instant (250 millisecondes) avant le décompte d’un autre appui sur le bouton pour être sûr de ne pas prendre en compte les rebonds. C’est la deuxième solution qui a été choisie.

Figure 9 : Schéma du module Morse

Module accéléromètre

Il était prévu mais n’a pas été intégré dans le projet, faute de temps. Le joueur devait bouger un cube en fonction des indications de l’autre joueur. Ce module aurait rajouté une véritable dimension physique au jeu par rapport à un jeu virtuel. L’intention initiale était de faire des translations du cube dans l’espace. Or l’accéléromètre ne relève que l’accélération et l’orientation dans l’espace. Il n’était pas possible de relever avec précision les mouvements effectués. Nous avions donc adapté le manuel du démineur afin que le joueur doive effectuer des rotations du cube ce que l’accéléromètre permettait de faire avec plus de précision.

Une bibliothèque Arduino est dédiée à l’accéléromètre. Après avoir inclus la bibliothèque et initialisé l’accéléromètre il suffit de relever les valeurs relevées par celui-ci. Le joueur aurait dû mettre le cube dans la position indiquée par le manuel et appuyer sur un bouton pour relever la valeur des positions selon les axes X, Y et Z.

Gérer plusieurs modules en même temps :

Voici la partie la plus compliquée que nous ayons eu à réaliser.

La fonction delay est une fonction bloquante qui ne permet pas d’effectuer plusieurs tâches en parallèle. Ainsi, à chaque émulation de son le programme se gelait entièrement (l’afficheur 7 segments était principalement impacté). Nous avons donc opté pour l’utilisation de la fonction millis qui gère le temps sans être une fonction bloquante selon le modèle :

Pour expliquer ce concept, voici un programme non bloquant :


Figure 11 : Programme de deux Leds clignotant de manière désynchronisée

Ici, les 2 LEDs clignotent de manière complètement indépendante. Avec la fonction delay, il serait impossible de réaliser un tel programme.
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

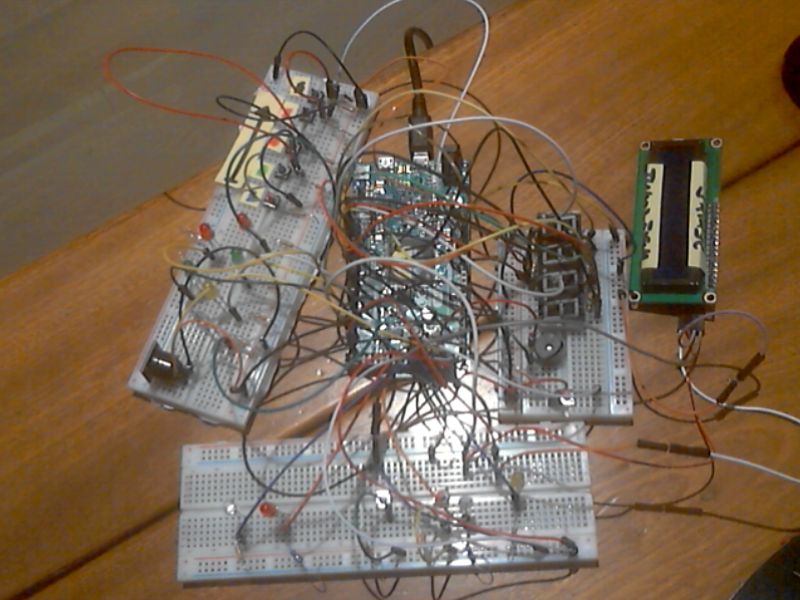
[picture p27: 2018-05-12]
bomb_defusal_game_v1/circuit/real/bomb_defusal_real.jpg

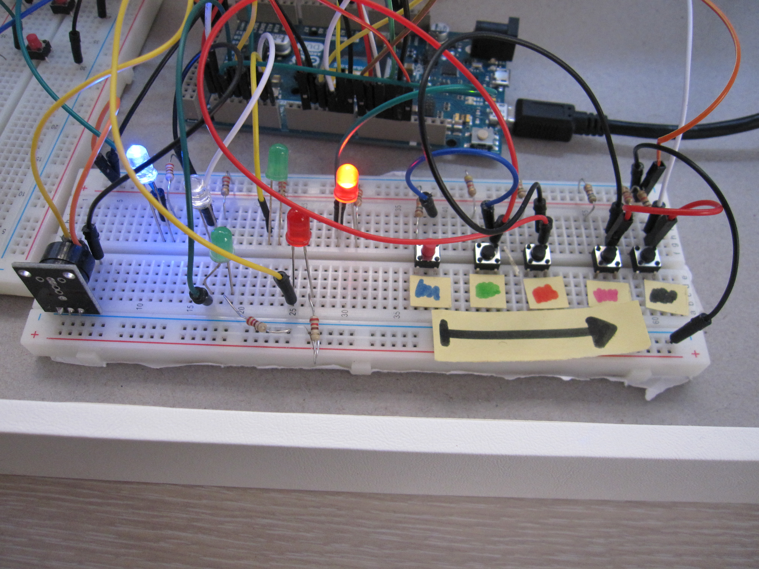
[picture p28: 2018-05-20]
bomb_defusal_game_v1/circuit/real/keyboard.JPG

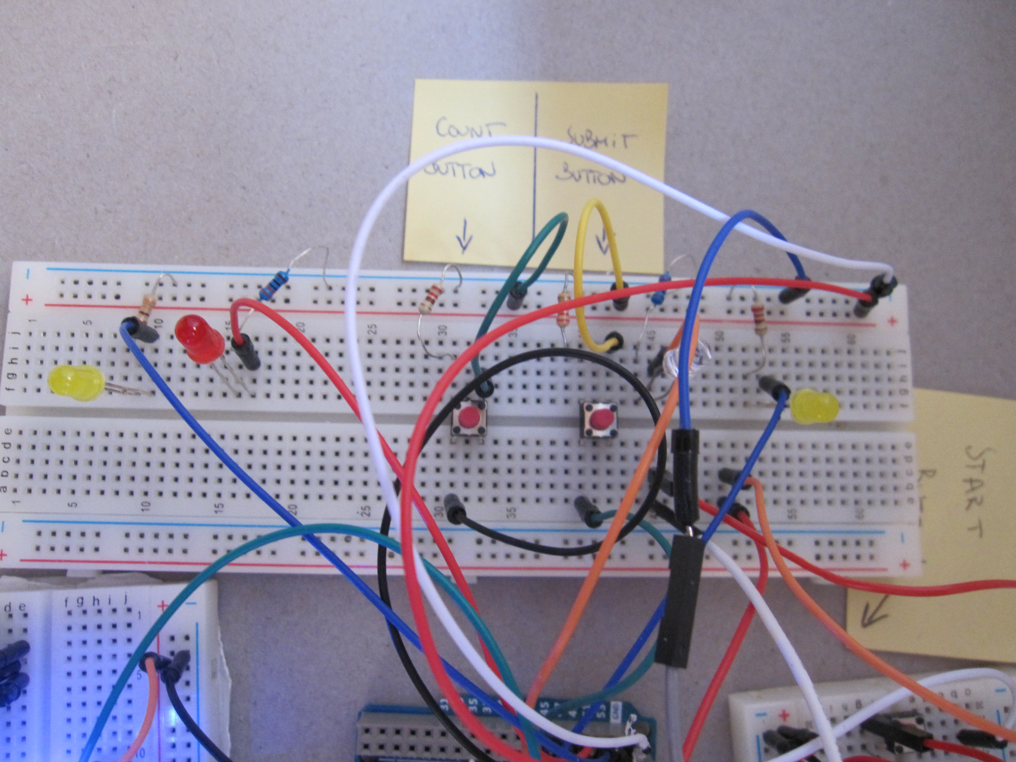
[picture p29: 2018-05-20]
bomb_defusal_game_v1/circuit/real/morse.JPG

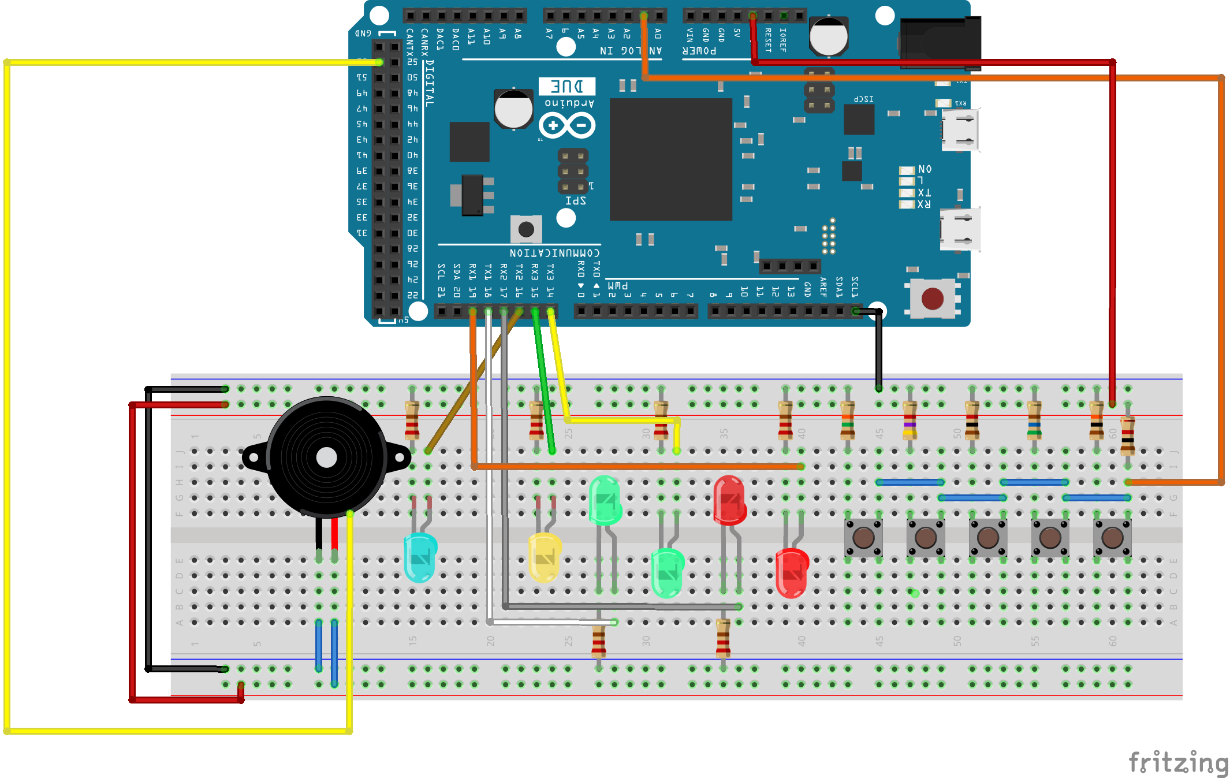
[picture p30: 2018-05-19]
bomb_defusal_game_v1/circuit/piano.png

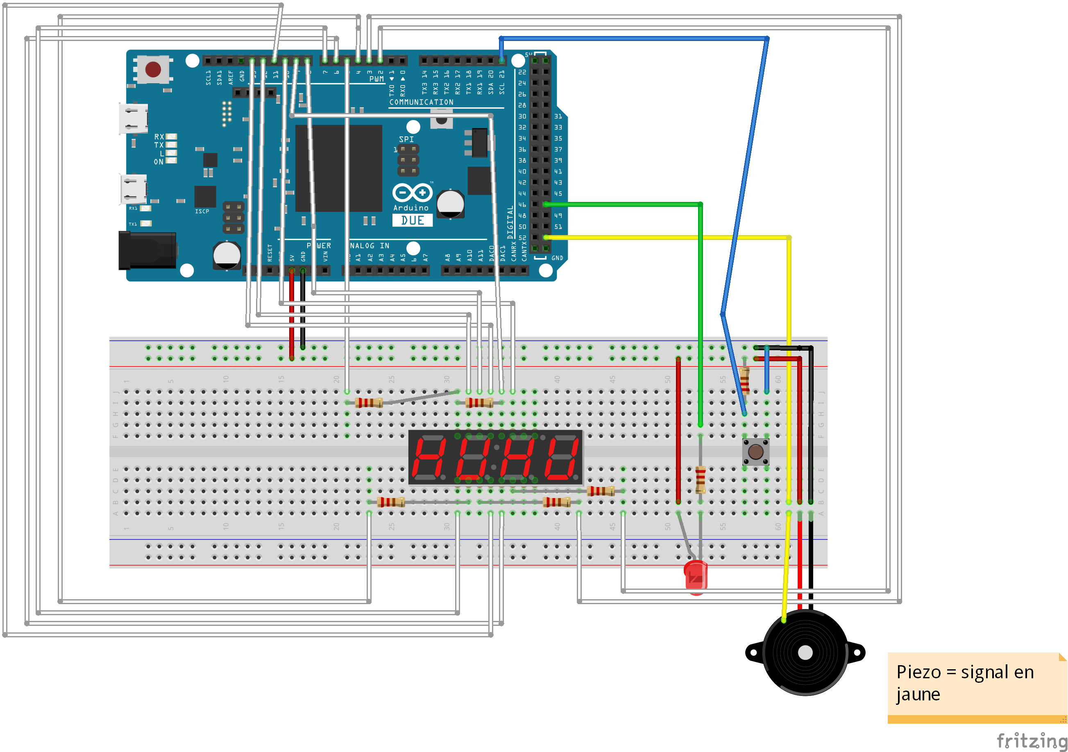
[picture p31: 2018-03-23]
programme_arduino/timer/schema/timer_bb.png

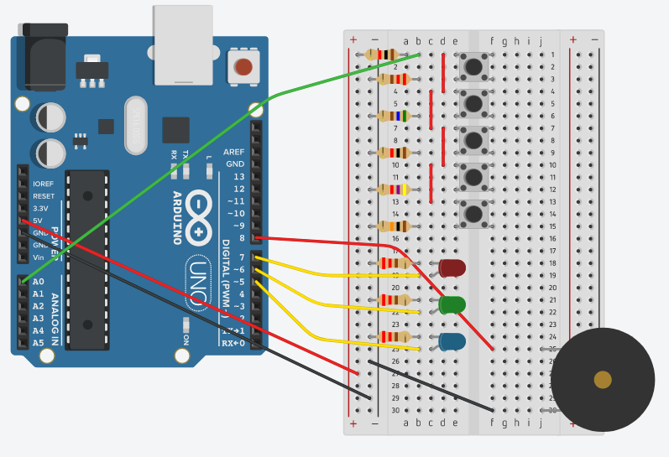
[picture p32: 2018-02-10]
programme_arduino/keyboard_module/keyboard_module_uno/circuit/circuit.png

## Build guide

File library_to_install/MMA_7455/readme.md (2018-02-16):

# Freescale 3-axis accelerometer MMA7455 library for Arduino
> A serious MMA7455 arduino library

## Features
* Support both I2C and SPI protocol
* Get the 8-bit and 10-bit values of each axis
* Get the value in 'g' for each axis
* Support the standard measurement mode
* Support the level mode (with interrupts)
* Support the pulse mode (with interrupts)
* Support the double pulse mode (with interrupts)

## Limitations
* The library relies on the standard Arduino libraries: the Wire library (for I2C) and the SPI library.
* Particle SparkCore has some performance issues with this library (and I don't know why), however the Particle Photon works wonderfully.
* The SPI feature works only with a 3.3v logic level, this is an hardware limitation of the MMA7455.

## Hardware tested
* Arduino Uno (I2C only)
* Arduino Duemilanove (I2C only)
* Arduino Pro Mini 3.3v (I2C and SPI)
* Particle Photon (I2C and SPI)
* *Note: If your board is not mentioned in the list,
it doesn't mean it won't work with yours, it just means I didn't try it
because I don't have every Arduino board on planet Earth.*

## Examples
* MMA7455_Demo: Simply display the 10-bit raw value and the 'g' value for each axis in measurement mode.
* MMA7455_AutoCalibration: Let it run to determine the offset values of your accelerometer.
* MMA7455_InterruptLevel: Illustrate the level mode and the interrupts.
* MMA7455_InterruptPulse: Illustrate the pulse mode and the interrupts.
* MMA7455_InterruptDoublePulse: Illustrate the double pulse mode and the interrupts.

## How-to use it?
1. Download the library
2. Extract and rename the folder to "MMA_7455".
3. Place the renamed folder in arduino/libraries/
4. Open the arduino IDE
5. Open MMA7455_Demo sample code
6. Upload it in your arduino board
7. Open a serial console set at 9600 baud
8. See the live value of the 3 axis

## License GPLv2
```
  Freescale 3-Axis Accelerometer MMA7455 Library designed for Arduino
  Copyright (C) 2015  Alexandre Boni
  
  This program is free software; you can redistribute it and/or modify
  it under the terms of the GNU General Public License as published by
  the Free Software Foundation; either version 2 of the License, or
  (at your option) any later version.
  
  This program is distributed in the hope that it will be useful,
  but WITHOUT ANY WARRANTY; without even the implied warranty of
  MERCHANTABILITY or FITNESS FOR A PARTICULAR PURPOSE.  See the
  GNU General Public License for more details.
  
  You should have received a copy of the GNU General Public License along
  with this program; if not, write to the Free Software Foundation, Inc.,
  51 Franklin Street, Fifth Floor, Boston, MA 02110-1301 USA.
```

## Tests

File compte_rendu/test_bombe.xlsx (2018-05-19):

N° Partie | Joueurs |  | Temps (en min) |  |  | Remarques |  | Modifications
 |  |  | Temps total | Temps Morse | Temps Piano | Rmq (en cours de jeu) | Rmq (après jeu) | Modifications manuels | Modifications programme
1 | Papa | Maman | 6 (explosée) | 6 | NON TROUVE | Difficulté à lire le morse | Manuel non clair | Changements : rôle + clair des deux joueurs / morse tourne continuellement | Augmentation espace entre les lettres
2 |  |  | XXX |  |  | Bug : Bouton Keyboard s'active tout seul |  |  | Résolution bug bouton keyboard
3 |  |  | 6 (explosée) | 3 | NON TROUVE | Morse trouvé facilement |  |  | Diminution espace entre les lettres
4 |  |  | 6 (explosée) | NON TROUVE | NON TROUVE | Morse trop dur
5 |  |  | 6 (explosée) | NON TROUVE | NON TROUVE | Morse trop dur |  |  | Augmentation espace entre les lettres
6 |  |  | 6 (explosée) | NON TROUVE | 3 |  |  | Rajout sens bouton keyboard
7 |  |  | XXX |  |  | Confusion entre "1" et "l" |  |  | "l" devenu "L"
8 |  |  | Trouvée : 6' restantes | 4 | 2 | Déchiffrage led trop facile |  | Rajout schémas module | Rajout du diagramme (2nde partie module keyboard)
 |  |  |  |  |  |  |  |  | Rajout : led erreur / validation du morse / compte morse /
 | Thibault | Maman
9 |  |  | 6 (explosée) | 5 | NON TROUVE | Pas le temps pour le piano | Morse : mieux
10 |  |  | Trouvée : 2'30 restantes | 1'30 | 2' | Beaucoup trop facile le morse pour Thibault |  |  | Diminution espace entre les lettres

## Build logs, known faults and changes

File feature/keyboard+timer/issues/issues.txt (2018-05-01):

Differents issues encountered :

- l.37 (main)
"Morse morse;"

observation : when this line is no longer commented on, the program still compiles but no longer shows anything

idea: wrong syntax?

- State Timer Sound (timer.h)

observation : The module arrives in the state but once inside, the condition:
"if (current_time - last_time_note_playing_updated_> = delayValue)"
is never satisfied

Using the serial monitor, we see that delayValue = 1515 and currentTime >> delayValue (and last_time_note_playing_updated_ initialized to 0).

idea : ??

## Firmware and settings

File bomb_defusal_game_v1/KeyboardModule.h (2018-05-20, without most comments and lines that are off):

#define Keyboard_h
#include "buzz.h"
#include "Arduino.h"
#include "timer.h"
#include <Wire.h>
#include<LiquidCrystal_I2C.h>
LiquidCrystal_I2C lcd_keyboard(0x27, 20, 2); //SERIAL NUMBER : KEYBOARD
LiquidCrystal_I2C lcd_morse_and_error(0x27, 20, 2); //COMPTEUR MORSE + ERROR COUNT
#define DEFAULT_BEEP_DURATION 120
#define DEFAULT_BEEP_FREQUENCY 440
enum
{
  DO, RE, MI, FA, SOL
};
int NOTE_FREQUENCIES[] = {262, 294, 330, 349, 392};
const int speaker_pin = 53;
const int num_leds = 6;
const int led_pins[num_leds] = {19, 14, 15, 16, 17, 18}; // Red, Green, Yellow, White, Error, Victory
const int BUTTONS_PIN = A1;
const int BUTTONS_TOTAL = 5;
const int BUTTONS_VALUES[BUTTONS_TOTAL] = {196, 430, 573, 855, 962};
AnalogMultiButton button_keyboard(BUTTONS_PIN, BUTTONS_TOTAL, BUTTONS_VALUES);
const byte CODE_LENGTH=9;
const byte CODE_DB_SIZE=9;
const byte CODE_DB[CODE_LENGTH * CODE_DB_SIZE] =
    {DO, RE, MI, RE, DO, MI, RE, RE, DO, //AU CLAIR DE LA LUNE
     DO, DO, RE, DO, FA, MI, DO, DO, RE, //FRERES JACQUES
     MI, MI, FA, SOL, SOL, FA, MI, RE, DO, //ODE A LA JOIE
     MI, FA, SOL, FA, MI, RE, MI, RE, MI, //OLE
     DO, SOL, FA, DO, MI, MI, RE, DO, SOL, //HASARD
     DO, SOL, SOL, FA, RE, FA, SOL, RE, MI, //SUZUKI
     MI, FA, SOL, SOL, MI, SOL, DO, SOL, MI, //FORREST GUMP
     RE, SOL, FA, DO, MI, SOL, MI, FA, DO, //HASARD
     MI, RE, DO, RE, MI, RE, MI, SOL, SOL}; //HASARD
class Keyboard
{
  public:
    enum State
    {
      PAUSE, GAME, NOTE_PLAYING, CHECK_INPUT_VALUE, PLAY_FEEDBACK_CORRECT, PLAY_FEEDBACK_WRONG, CODE_FOUND
    };
    Keyboard() {}
    Keyboard(int num_inputs, int speaker_pin,
             int num_leds, const int* led_pins)
    {
      if(num_inputs > 8)
      {
        Serial.println("Error: maximum number of keyboard inputs supported is 8!");
        return;
      }
      num_inputs_ = num_inputs;
      speaker_pin_ = speaker_pin;
      num_leds_ = num_leds;
      led_pins_ = led_pins;
      pinMode(speaker_pin_, OUTPUT);
      for(int i=0; i<num_leds_;++i)
      {
        pinMode(led_pins_[i], OUTPUT);
      }
      reset();
    }
    int codeValueAt(int index)
    {
        return (int) CODE_DB[code_index_ * CODE_LENGTH + index];
    }
    void reset()
    {
      state_ = PAUSE;
    }
   void start()
   {
    if (state_ == PAUSE){ //Game is on pause
        last_time_note_playing_updated_ = 0;
        digitalWrite(speaker_pin_,LOW);
        current_cycle_number_ = 0;
        first_time_play_feedback_correct_ = true;
        first_time_play_feedback_wrong_ = true;
        index_next_button_in_code_ = 0;
        error_count_keyboard_= 0;
        keyboard_solved_ = false;
        code_index_ = random(0, 9);
        Serial.println("Keyboard : ");
        Serial.print("Selected code : ");
        Serial.println(code_index_);
        indicateNumberWithLedsCode(code_index_);
        shift_ = random(0,5);
        Serial.print("Selected shift : ");
        Serial.println(shift_);
        indicateNumberWithLedsShift(shift_);
        state_ = GAME;
        return;
    }
   }
   void update_keyboard()
    {
      if (state_ == PAUSE){ //Game is on pause
        return;
      }
      else if(state_ == GAME){
          button_keyboard.update();
          for(int i=0; i<BUTTONS_TOTAL; ++i)
          {
              if(button_keyboard.onPress(i))
              {
                  input_value_ = (num_inputs_ - 1) - i;
                  input_value_ = (input_value_ + num_inputs_ - shift_) % num_inputs_;
                  state_ = NOTE_PLAYING;
                  return;
              }
          }
       return;
      }
      else if(state_ == NOTE_PLAYING)
      {
        int frequency = NOTE_FREQUENCIES[input_value_];
        long delayValue = 1000000 / frequency / 2; //delay in microsecondes
        long numCycles = frequency * note_duration / 1000;
        unsigned long current_time = micros();
        if(current_time - last_time_note_playing_updated_ >= delayValue)
        {
          int state_targetpin = digitalRead(speaker_pin_);
          if (state_targetpin == HIGH)
          {
            digitalWrite(speaker_pin_,LOW);
            current_cycle_number_ ++;
          }
          else
          {
            digitalWrite(speaker_pin_,HIGH);
          }
        last_time_note_playing_updated_ = micros();
        }
        if(current_cycle_number_ == numCycles)
        {
          state_ = CHECK_INPUT_VALUE;
          current_cycle_number_ = 0;
          last_time_note_playing_updated_ = 0;
          digitalWrite(speaker_pin_,LOW);   //this is not necessary
        }
        return;
      }
      else if(state_ == CHECK_INPUT_VALUE)
      {
        if(input_value_ == codeValueAt(index_next_button_in_code_)) // has the user hit the next key in the sequence?
        {
            Serial.print("Keyboard : Correct input => ");
            Serial.print(index_next_button_in_code_ + 1);
            Serial.print(" / ");
            Serial.println(CODE_LENGTH);
            index_next_button_in_code_++;
            if(index_next_button_in_code_ == CODE_LENGTH) // is that the last key of the sequence?
            {
              Serial.println("Keyboard Solved");
              keyboard_solved_ = true;
              state_ = CODE_FOUND;
            }
            else
            {
              state_ = PLAY_FEEDBACK_CORRECT;
            }
        }
        else
        {
            Serial.println("Keyboard : Wrong input. Start again from scratch.");
            state_ = PLAY_FEEDBACK_WRONG;
            index_next_button_in_code_ = 0;
            error_count_keyboard_ ++;
            Serial.println("Number of errors :");
            Serial.println(error_count_keyboard_);
        }
      }
      else if(state_ == PLAY_FEEDBACK_CORRECT)
      {
        if(first_time_play_feedback_correct_) //means if(first_time_play_feedback_correct_ == true)
        {
          previousMillis_correct_led_ = millis();
          first_time_play_feedback_correct_ = false;
        }
        unsigned long currentMillis_correct_led = millis();
        digitalWrite(led_pins_[5], HIGH);
        if (currentMillis_correct_led - previousMillis_correct_led_ >= note_duration)
        {
          digitalWrite(led_pins_[5], LOW);
          first_time_play_feedback_correct_ = true;
          state_ = GAME;
        }
      }
      else if(state_ == PLAY_FEEDBACK_WRONG)
      {
        if(first_time_play_feedback_wrong_ == true)
        {
          previousMillis_error_led_ = millis();
          first_time_play_feedback_wrong_ = false;
        }
        unsigned long currentMillis_error_led = millis();
        digitalWrite(led_pins_[4], HIGH);
        if (currentMillis_error_led - previousMillis_error_led_ >= note_duration)
        {
          digitalWrite(led_pins_[4], LOW);
          first_time_play_feedback_wrong_ = true;
          state_ = GAME;
        }
      }
      else if(state_ == CODE_FOUND){
        digitalWrite(led_pins_[4], HIGH);
        digitalWrite(led_pins_[5], HIGH);
        state_ = PAUSE;
      }
  }
    void indicateNumberWithLedsCode (int number) //INDICATION : BINARY MODE
    {
      if(number == 0) //A
      {
        digitalWrite(led_pins_[0],HIGH);
        digitalWrite(led_pins_[1],LOW);
        digitalWrite(led_pins_[2],HIGH);
        digitalWrite(led_pins_[3],HIGH);
      }
      if(number == 1) //B
      {
        digitalWrite(led_pins_[0],HIGH);
        digitalWrite(led_pins_[1],LOW);
        digitalWrite(led_pins_[2],HIGH);
        digitalWrite(led_pins_[3],LOW);
      }
      if(number == 2) //C
      {
        digitalWrite(led_pins_[0],LOW);
        digitalWrite(led_pins_[1],LOW);
        digitalWrite(led_pins_[2],HIGH);
        digitalWrite(led_pins_[3],HIGH);
      }
      if(number == 3) //D
      {
        digitalWrite(led_pins_[0],LOW);
        digitalWrite(led_pins_[1],HIGH);
        digitalWrite(led_pins_[2],LOW);
        digitalWrite(led_pins_[3],HIGH);
      }
      if(number == 4) //E
      {
        digitalWrite(led_pins_[0],LOW);
        digitalWrite(led_pins_[1],LOW);
        digitalWrite(led_pins_[2],LOW);
        digitalWrite(led_pins_[3],LOW);
      }
      if(number == 5) //F
      {
        digitalWrite(led_pins_[0],LOW);
        digitalWrite(led_pins_[1],HIGH);
        digitalWrite(led_pins_[2],HIGH);
        digitalWrite(led_pins_[3],HIGH);
      }
      if(number == 6) //G
      {
        digitalWrite(led_pins_[0],HIGH);
        digitalWrite(led_pins_[1],HIGH);
        digitalWrite(led_pins_[2],HIGH);
        digitalWrite(led_pins_[3],HIGH);
      }
      if(number == 7) //H
      {
        digitalWrite(led_pins_[0],LOW);
        digitalWrite(led_pins_[1],LOW);
        digitalWrite(led_pins_[2],LOW);
        digitalWrite(led_pins_[3],HIGH);
      }
      if(number == 8) //I
      {
        digitalWrite(led_pins_[0],HIGH);
        digitalWrite(led_pins_[1],LOW);
        digitalWrite(led_pins_[2],LOW);
        digitalWrite(led_pins_[3],HIGH);
      }
    }
    void indicateNumberWithLedsShift (int number)
    {
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

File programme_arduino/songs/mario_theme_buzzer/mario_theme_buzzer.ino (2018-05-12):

/*************************************************
 * Public Constants
 *************************************************/
 
#define NOTE_B0  31
#define NOTE_C1  33
#define NOTE_CS1 35
#define NOTE_D1  37
#define NOTE_DS1 39
#define NOTE_E1  41
#define NOTE_F1  44
#define NOTE_FS1 46
#define NOTE_G1  49
#define NOTE_GS1 52
#define NOTE_A1  55
#define NOTE_AS1 58
#define NOTE_B1  62
#define NOTE_C2  65
#define NOTE_CS2 69
#define NOTE_D2  73
#define NOTE_DS2 78
#define NOTE_E2  82
#define NOTE_F2  87
#define NOTE_FS2 93
#define NOTE_G2  98
#define NOTE_GS2 104
#define NOTE_A2  110
#define NOTE_AS2 117
#define NOTE_B2  123
#define NOTE_C3  131
#define NOTE_CS3 139
#define NOTE_D3  147
#define NOTE_DS3 156
#define NOTE_E3  165
#define NOTE_F3  175
#define NOTE_FS3 185
#define NOTE_G3  196
#define NOTE_GS3 208
#define NOTE_A3  220
#define NOTE_AS3 233
#define NOTE_B3  247
#define NOTE_C4  262
#define NOTE_CS4 277
#define NOTE_D4  294
#define NOTE_DS4 311
#define NOTE_E4  330
#define NOTE_F4  349
#define NOTE_FS4 370
#define NOTE_G4  392
#define NOTE_GS4 415
#define NOTE_A4  440
#define NOTE_AS4 466
#define NOTE_B4  494
#define NOTE_C5  523
#define NOTE_CS5 554
#define NOTE_D5  587
#define NOTE_DS5 622
#define NOTE_E5  659
#define NOTE_F5  698
#define NOTE_FS5 740
#define NOTE_G5  784
#define NOTE_GS5 831
#define NOTE_A5  880
#define NOTE_AS5 932
#define NOTE_B5  988
#define NOTE_C6  1047
#define NOTE_CS6 1109
#define NOTE_D6  1175
#define NOTE_DS6 1245
#define NOTE_E6  1319
#define NOTE_F6  1397
#define NOTE_FS6 1480
#define NOTE_G6  1568
#define NOTE_GS6 1661
#define NOTE_A6  1760
#define NOTE_AS6 1865
#define NOTE_B6  1976
#define NOTE_C7  2093
#define NOTE_CS7 2217
#define NOTE_D7  2349
#define NOTE_DS7 2489
#define NOTE_E7  2637
#define NOTE_F7  2794
#define NOTE_FS7 2960
#define NOTE_G7  3136
#define NOTE_GS7 3322
#define NOTE_A7  3520
#define NOTE_AS7 3729
#define NOTE_B7  3951
#define NOTE_C8  4186
#define NOTE_CS8 4435
#define NOTE_D8  4699
#define NOTE_DS8 4978
 
#define melodyPin 50
//Mario main theme melody
int melody[] = {
  NOTE_E7, NOTE_E7, 0, NOTE_E7,
  0, NOTE_C7, NOTE_E7, 0,
  NOTE_G7, 0, 0,  0,
  NOTE_G6, 0, 0, 0,
 
  NOTE_C7, 0, 0, NOTE_G6,
  0, 0, NOTE_E6, 0,
  0, NOTE_A6, 0, NOTE_B6,
  0, NOTE_AS6, NOTE_A6, 0,
 
  NOTE_G6, NOTE_E7, NOTE_G7,
  NOTE_A7, 0, NOTE_F7, NOTE_G7,
  0, NOTE_E7, 0, NOTE_C7,
  NOTE_D7, NOTE_B6, 0, 0,
 
  NOTE_C7, 0, 0, NOTE_G6,
  0, 0, NOTE_E6, 0,
  0, NOTE_A6, 0, NOTE_B6,
  0, NOTE_AS6, NOTE_A6, 0,
 
  NOTE_G6, NOTE_E7, NOTE_G7,
  NOTE_A7, 0, NOTE_F7, NOTE_G7,
  0, NOTE_E7, 0, NOTE_C7,
  NOTE_D7, NOTE_B6, 0, 0
};
//Mario main them tempo
int tempo[] = {
  12, 12, 12, 12,
  12, 12, 12, 12,
  12, 12, 12, 12,
  12, 12, 12, 12,
 
  12, 12, 12, 12,
  12, 12, 12, 12,
  12, 12, 12, 12,
  12, 12, 12, 12,
 
  9, 9, 9,
  12, 12, 12, 12,
  12, 12, 12, 12,
  12, 12, 12, 12,
 
  12, 12, 12, 12,
  12, 12, 12, 12,
  12, 12, 12, 12,
  12, 12, 12, 12,
 
  9, 9, 9,
  12, 12, 12, 12,
  12, 12, 12, 12,
  12, 12, 12, 12,
};
//Underworld melody
int underworld_melody[] = {
  NOTE_C4, NOTE_C5, NOTE_A3, NOTE_A4,
  NOTE_AS3, NOTE_AS4, 0,
  0,
  NOTE_C4, NOTE_C5, NOTE_A3, NOTE_A4,
  NOTE_AS3, NOTE_AS4, 0,
  0,
  NOTE_F3, NOTE_F4, NOTE_D3, NOTE_D4,
  NOTE_DS3, NOTE_DS4, 0,
  0,
  NOTE_F3, NOTE_F4, NOTE_D3, NOTE_D4,
  NOTE_DS3, NOTE_DS4, 0,
  0, NOTE_DS4, NOTE_CS4, NOTE_D4,
  NOTE_CS4, NOTE_DS4,
  NOTE_DS4, NOTE_GS3,
  NOTE_G3, NOTE_CS4,
  NOTE_C4, NOTE_FS4, NOTE_F4, NOTE_E3, NOTE_AS4, NOTE_A4,
  NOTE_GS4, NOTE_DS4, NOTE_B3,
  NOTE_AS3, NOTE_A3, NOTE_GS3,
  0, 0, 0
};
//Underwolrd tempo
int underworld_tempo[] = {
  12, 12, 12, 12,
  12, 12, 6,
  3,
  12, 12, 12, 12,
  12, 12, 6,
  3,
  12, 12, 12, 12,
  12, 12, 6,
  3,
  12, 12, 12, 12,
  12, 12, 6,
  6, 18, 18, 18,
  6, 6,
  6, 6,
  6, 6,
  18, 18, 18, 18, 18, 18,
  10, 10, 10,
  10, 10, 10,
  3, 3, 3
};
 
void setup(void)
{
  pinMode(50, OUTPUT);//buzzer
  pinMode(44, OUTPUT);//led indicator when singing a note
 
}
void loop()
{
  //sing the tunes
  sing(1);
  sing(1);
  sing(2);
}
int song = 0;
 
void sing(int s) {
  // iterate over the notes of the melody:
  song = s;
  if (song == 2) {
    Serial.println(" 'Underworld Theme'");
    int size = sizeof(underworld_melody) / sizeof(int);
    for (int thisNote = 0; thisNote < size; thisNote++) {
 
      // to calculate the note duration, take one second
      // divided by the note type.
      //e.g. quarter note = 1000 / 4, eighth note = 1000/8, etc.
      int noteDuration = 1000 / underworld_tempo[thisNote];
 
      buzz(melodyPin, underworld_melody[thisNote], noteDuration);
 
      // to distinguish the notes, set a minimum time between them.
      // the note's duration + 30% seems to work well:
      int pauseBetweenNotes = noteDuration * 1.30;
      delay(pauseBetweenNotes);
 
      // stop the tone playing:
      buzz(melodyPin, 0, noteDuration);
 
    }
 
  } else {
 
    Serial.println(" 'Mario Theme'");
    int size = sizeof(melody) / sizeof(int);
    for (int thisNote = 0; thisNote < size; thisNote++) {
 
      // to calculate the note duration, take one second
      // divided by the note type.
      //e.g. quarter note = 1000 / 4, eighth note = 1000/8, etc.
      int noteDuration = 1000 / tempo[thisNote];
 
      buzz(melodyPin, melody[thisNote], noteDuration);
 
      // to distinguish the notes, set a minimum time between them.
      // the note's duration + 30% seems to work well:
      int pauseBetweenNotes = noteDuration * 1.30;
      delay(pauseBetweenNotes);
 
      // stop the tone playing:
      buzz(melodyPin, 0, noteDuration);
 
    }
  }
}
 
void buzz(int targetPin, long frequency, long length) {
  digitalWrite(44, HIGH);
  long delayValue = 1000000 / frequency / 2; // calculate the delay value between transitions

  //// 1 second's worth of microseconds, divided by the frequency, then split in half since
  //// there are two phases to each cycle
  long numCycles = frequency * length / 1000; // calculate the number of cycles for proper timing
  //// multiply frequency, which is really cycles per second, by the number of seconds to
  //// get the total number of cycles to produce
  for (long i = 0; i < numCycles; i++) { // for the calculated length of time...
    digitalWrite(targetPin, HIGH); // write the buzzer pin high to push out the diaphram
    delayMicroseconds(delayValue); // wait for the calculated delay value
    digitalWrite(targetPin, LOW); // write the buzzer pin low to pull back the diaphram
    delayMicroseconds(delayValue); // wait again or the calculated delay value
  }
  digitalWrite(44, LOW);
 
}

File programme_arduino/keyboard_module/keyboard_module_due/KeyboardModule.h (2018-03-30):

#ifndef Keyboard_h
#define Keyboard_h

#include "buzz.h"
#include "Arduino.h"

#define DEFAULT_BEEP_DURATION 120
#define DEFAULT_BEEP_FREQUENCY 440

enum
{
  DO, RE, MI, FA, SOL
};

// DO, RE, MI, FA, SOL
int NOTE_FREQUENCIES[] = {262, 294, 330, 349, 392};

const int note_duration = 165;

// Dictionary of codes
// A random dictionary can be generated using the python script in scripts/generate_random_dictionary.py
const byte CODE_LENGTH=9;
const byte CODE_DB_SIZE=7;
const byte CODE_DB[CODE_LENGTH * CODE_DB_SIZE] = 
    {SOL, SOL, SOL, SOL, SOL, SOL, SOL, SOL, SOL, 
     MI, FA, FA, DO, SOL, RE, SOL, FA, DO, 
     FA, SOL, DO, DO, FA, RE, RE, MI, MI, 
     SOL, RE, FA, SOL, DO, SOL, DO, DO, SOL, 
     RE, RE, RE, RE, RE, RE, RE, RE, RE, 
     RE, SOL, SOL, DO, MI, SOL, MI, MI, DO, 
     RE, SOL, RE, SOL, SOL, MI, MI, FA, MI};



class Keyboard
{  
  public:

    enum Result
    {
      CORRECT_INPUT, WRONG_INPUT, CODE_FOUND
    };

    Keyboard() {}

    Keyboard(int num_inputs, int speaker_pin,
             int num_leds, const int* led_pins)
    {
      if(num_inputs > 8)
      {
        Serial.println("Error: maximum number of keyboard inputs supported is 8!");
        return;
      }
      
      num_inputs_ = num_inputs; // global to local --> _
      speaker_pin_ = speaker_pin;
      num_leds_ = num_leds;
      led_pins_ = led_pins;

      pinMode(speaker_pin_, OUTPUT);
      for(int i=0; i<num_leds_;++i) // définit le output à chaque led 
      {
        pinMode(led_pins_[i], OUTPUT);
      }
      
      reset(); // fonction définie plus bas
    }

    int codeValueAt(int index)
    {
        return (int) CODE_DB[code_index_ * CODE_LENGTH + index];
    }
    
    void reset()
    {
      playResetSequence();
      
      index_next_button_in_code_ = 0;

      // Choose a code randomly among the ones in the database
      code_index_ = random(1, CODE_DB_SIZE);
      Serial.print("Selected code: ");
      Serial.println(code_index_);

      // Indicate the sequence and shift value to the user
      indicateNumberWithLeds(code_index_);

      // Generate a random shift
      shift_ = random(1, num_inputs_)-1;
      Serial.print("Selected shift: ");
      Serial.println(shift_);

      indicateNumberWithLeds(shift_);
      
      setLeds(LOW, LOW, LOW);
    }

    void playNote(int input_value)
    {
      buzz(speaker_pin_, NOTE_FREQUENCIES[input_value],note_duration);
      //delay(note_duration);
      //noTone(speaker_pin_);
    }

    Result newInput(int input_value)
    {
      // reverse the button order so that the keyboard reads from left ro right when looking towards the Arduino
      input_value = (num_inputs_ - 1) - input_value;

      // shift the buttons so that button number i (starting from zero) corresponds to the note 'DO'
      input_value = (input_value + num_inputs_ - shift_) % num_inputs_;

      playNote(input_value);
      
      if(input_value == codeValueAt(index_next_button_in_code_)) // has the user hit the next key in the sequence?
      {
        Serial.print("Correct input => ");
        Serial.print(index_next_button_in_code_ + 1);
        Serial.print(" / ");
        Serial.println(CODE_LENGTH);
        
        index_next_button_in_code_++;

        if(index_next_button_in_code_ == CODE_LENGTH) // is that the last key of the sequence?
        {
          Serial.println("Congrats, you completed the code!");
          
          playVictorySequence();
          reset();
          
          return CODE_FOUND;
        }
        else
        {
          return CORRECT_INPUT;
        }
      }
      else
      {
        Serial.println("Wrong input. Start again from scratch.");
        
        index_next_button_in_code_ = 0;
        playErrorSequence();

        return WRONG_INPUT;
      }
    }

    void indicateNumberWithLeds(int number)
    {
      // Indicate a number to the user by switching on a set of leds.
      //
      // We look at the last num_leds_ digits in the binary representation of number
      // and activate some of the LEDs based on these values.
      //
      
      if(number == 0)
      {
        // to avoid having no leds switched on when the number is 0
        // (which would be confusing for the user),
        // we replace zero with the max value in the range
        // so that all leds will be switched on instead
        
        number = bit(num_leds_)-1;
      }
      
      for(int i=0; i<num_leds_; ++i)
      {
        if (number & (1 << i))  // if bit i is set
        {
          digitalWrite(led_pins_[i], HIGH);
        }
        else
        {
          digitalWrite(led_pins_[i], LOW);
        }
      }

      buzz(speaker_pin_, DEFAULT_BEEP_FREQUENCY,DEFAULT_BEEP_DURATION);
      //delay(DEFAULT_BEEP_DURATION);
      //noTone(speaker_pin_);

      delay(1800);
      
    }

    void blinkLedAndBeep(int led_pin, int speaker_pin, int duration, int beep_frequency=DEFAULT_BEEP_FREQUENCY)
    {
      digitalWrite(led_pin, HIGH);
      buzz(speaker_pin, beep_frequency,duration);
      //digitalWrite(led_pin, HIGH);
      //delay(duration);

      //noTone(speaker_pin);
      digitalWrite(led_pin, LOW);
    }

    void playResetSequence()
    {
      for(int i=0; i<3; ++i)
      {
        for(int j=0; j<num_leds_; ++j)
        {
          blinkLedAndBeep(led_pins_[j], speaker_pin_, DEFAULT_BEEP_DURATION);
        }
      }
      delay(350);
    }

    void playErrorSequence()
    {
      const int red_led_pin_ = led_pins_[0];
      digitalWrite(red_led_pin_, HIGH);
      delay(note_duration);
      for(int i=0; i<2; ++i)
      {
        buzz(speaker_pin_, DEFAULT_BEEP_FREQUENCY,90);
        //delay(90);
        //noTone(speaker_pin_);
        delay(90);
      }
      digitalWrite(red_led_pin_, LOW);
    }
    
    void playVictorySequence()
    {
      const int green_led_pin_ = led_pins_[1];
      digitalWrite(green_led_pin_, HIGH);
      //noTone(speaker_pin_);
      delay(note_duration);
      for(int i=0; i<num_inputs_; ++i)
      {
        buzz(speaker_pin_, NOTE_FREQUENCIES[i],100);
        //delay(100);
      }
      for(int i=num_inputs_-2; i>=0; --i)
      {
        buzz(speaker_pin_, NOTE_FREQUENCIES[i],100);
        //delay(100);
      }
      //noTone(speaker_pin_);
      digitalWrite(green_led_pin_, LOW);
      delay(300);
    }

    void setLeds(int red_value, int green_value, int blue_led)
    {
      digitalWrite(led_pins_[0], red_value);
      digitalWrite(led_pins_[1], green_value);
      digitalWrite(led_pins_[2], blue_led);
    }


    int num_inputs_;
    int code_index_;
    int shift_;
    int index_next_button_in_code_;

    int speaker_pin_;
    int num_leds_;
    const int *led_pins_;
};


#endif

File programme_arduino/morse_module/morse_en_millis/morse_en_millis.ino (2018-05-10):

//https://forum.arduino.cc/index.php?topic=492308.0 morse
//https://www.carnetdumaker.net/articles/faire-plusieurs-choses-la-fois-avec-une-carte-arduino/ utilisation de la fontion millis
const int led = 51;  //led du morse
const int buzz = 6;
const int led2 = 49; //led verte qui indique si c'est réussi ou pas
const int temps = 250;   // Durée d'un point (durée de référence)
int bouton = 47; // bouton pour saisir le numéro du mot
byte etat;
byte etat2;
unsigned long previousMillis = 0;
unsigned long previousMillis2 = 0; 
int intervalle;
int intervalle2;
int compt = 0;
int compt2 = 0;
int inter;
int i = 0;
boolean module;
int buttonstate  = 0;
int alea;
int compteur = 0;
String message = "";  // Ne pas mettre d'accent dans le message

void setup() {

  module = false; // etat du module
  etat = HIGH;
  pinMode(bouton, INPUT);
  pinMode(buzz, OUTPUT);
  Serial.begin(9600);
  Serial.println("test1");
  randomSeed(analogRead(0));
  pinMode(led, OUTPUT); 
  pinMode(led2, OUTPUT);
  alea = random(1,9);
  Serial.print(alea);
  Serial.print(" --> ");
  switch (alea) { // les différents mots dans la fonciton switch case
    case 1:
      message = "TOTO";
      Serial.println(message);
      break;
    case 2:
      message = "CHIMIE";
      Serial.println(message);
      break;
    case 3:
      message = "TINTIN";
      Serial.println(message);
      break;
    case 4:
      message = "EPONGE";
      Serial.println(message);
      break;
    case 5:
      message = "MARTY";
      Serial.println(message);
      break;
    case 6:
      message = "MATHS";
      Serial.println(message);
      break;
    case 7:
      message = "PLAGE";
      Serial.println(message);
      break;
    case 8:
      message = "NEYMAR";
      Serial.println(message);
      break;
    case 9:
      message = "TIPE";
      Serial.println(message);
      break; 
  }
  
  message.toUpperCase();  // On transcrit tout le message en majuscule

  // On remplaceme chaque lettre du message par le code morse qui lui est attribué
  // Notez que j'ajoute un ";" volontairement à la fin afin de marquer la fin de la lettre dans le sequencage morse plus bas dans le code
  // on commence en toute logique par les "." et "-" et ";" qui sont dans votre message afin de ne pas remplacer les . ou - d'une lettre déjà convertie donc on commence par ça
  
  message.replace("A",".-;");
  message.replace("B","-...;");
  message.replace("C","-.-.;");
  message.replace("D","-..;");
  message.replace("E",".;");
  message.replace("F","..-.;");
  message.replace("G","--.;");
  message.replace("H","....;");
  message.replace("I","..;");
  message.replace("J",".---;");
  message.replace("K","-.-;");
  message.replace("L",".-..;");
  message.replace("M","--;");
  message.replace("N","-.;");
  message.replace("O","---;");
  message.replace("P",".--.;");
  message.replace("Q","--.-;");
  message.replace("R",".-.;");
  message.replace("S","...;");
  message.replace("T","-;");
  message.replace("U","..-;");
  message.replace("V","...-;");
  message.replace("W",".--;");
  message.replace("X","-..-;");
  message.replace("Y","-.--;");
  message.replace("Z","--..;");
  message.replace("1",".----;");
  message.replace("2","..---;");
  message.replace("3","...--;");
  message.replace("4","....-;");
  message.replace("5",".....;");
  message.replace("6","-....;");
  message.replace("7","--...;");
  message.replace("8","---..;");
  message.replace("9","----.;");
  message.replace("0","-----;");
  message.replace(" ","|");           // Ici le "|" indique la fin d'un mot et qu'il peut y en avoir un autre derrière car il y a un espace dans votre message  
  message.replace(":","---...;");
  message.replace(",","--..--;");
  message.replace("?","..--..;");
  message.replace("'",".----.;");
  message.replace("!","-.-.--;");
  message.replace("@",".--.-.;");

  message = message + "|";  // J'ajoute un "|" qui marquera la fin du mot ou du message et qui servira dans le sequencage morse plus bas dans le code

  // On remplace maintenant ";|" par "|" dans le message transformé car la fin de lettre ne sert à rien avant un autre mot
  message.replace(";|","|");

}

void loop() {    //message --> -.-.;....;..;--;..;.| message morse du mot chimie
digitalWrite(led, etat);
digitalWrite(led2,etat2);

buttonstate = digitalRead(bouton);
/*Serial.println("Button state :");
Serial.println(buttonstate);*/

unsigned long currentMillis = millis();
if (compt == 0 and compt2 ==0){
  if (message.substring(i, i+1) == "-" ) { // cas du "long"
    inter = 3*temps;
  }
  else if (message.substring(i, i+1) == "." ) { // cas du "court"
    inter = temps;
    }
  else if (message.substring(i, i+1) == ";" ) { //espace entre chaque lettre
    inter = 3*temps;
  }
  else if (message.substring(i, i+1) == "|" ) {//espacement de 7 temps entre chaque mots
    inter = 7*temps;
  }
}
  if(currentMillis - previousMillis >= inter and (message.substring(i,i+1) == "-" or message.substring(i, i+1) == ".") ) { // à chaque fois que le temps indique par inter est dépassé on change l'état de la led
    previousMillis = currentMillis;
    if (message.substring(i,i+1) == "-"){// comme le tiret se fait en deux temps différents je change la longueur du temps a attendre pour la deuxieme partie
      inter = temps;
    }
    etat = ! etat;
    ++compt;
  }
  else if (currentMillis - previousMillis >= inter and message.substring(i, i+1) == ";"){
    ++compt2;
    previousMillis = currentMillis;
  }
  else if (currentMillis - previousMillis >= inter and message.substring(i,i+1) == "|"){
    previousMillis = currentMillis;
    ++i;
  }
if (i == message.length()){ // je sais pas pourquoi il faut mettre -1 mais sinon ca boucle pas donc bon message length = 21 pour alea = 2 et ca s'arrete a 20
  i = 0; // on boucle
  etat = HIGH;
}
if ((compt == 2 or compt2 == 1) and (message.substring(i+1,i+2) == ";" or message.substring(i+1, i+2) == "|")){ // un tiret ou un point se font toujous en deux temps d'où les intervalles 1 et 2 et le compteur
  ++i; 
  compt=0;   //a chaque fois qu'un signal est transcrit on remet le compteur à 0 
  compt2 =0;
  etat = LOW; // comme le prochain caractère est un espacement avec la led éteinte je met l'état en low
}
else if ((compt == 2 or compt2 == 1) and (message.substring(i+1,i+2) == "-" or message.substring(i+1, i+2) == ".")){ 
  ++i;
  compt2 =0;
  compt = 0;
  etat = HIGH; // comme le prochain caractère et un tiret ou un point il faut mettre l'état en high
}

if (buttonstate == HIGH and currentMillis - previousMillis2 >=300){  // le temps de 300 millis sert a éviter le rebond (j'ai pas réussi avec les condensateurs masi bon ca marche bien logiciellement) 
  ++ compteur;
  previousMillis2 = currentMillis;
  Serial.print("Compteur is on ");
  Serial.println(compteur);
}
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

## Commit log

2018-01-25 programme_arduino_vrac
    Tous les programmes arduino en vrac
2018-01-25 ajout commentaire
    Ajout commentaire pour voir le programme LCD qui fonctionne sur la Due
2018-01-25 ajout schema
    [timer.fzz]
2018-01-29 accelerometre + morse
2018-02-13 ajout_manuel
    Transfert de l'ancien repository github des ebauches de manuel des différents modules
2018-02-19 les essais du morse
2018-03-12 rangement+keyboard
    rangement des fichiers
    transposition du module keyboard pour due
    [timer.fzz]
2018-03-12 ajout test analog multi button
2018-03-23 plusieurs changements et tests
    [morse.fzz, timer.fzz]
2018-04-12 morse millis
2018-04-12 ajout keyboard + timer !
2018-04-12 buzz_millis pas encore fonctionnel
    [buzz.h]
2018-04-12 button timer => analog multi button
2018-04-12 2 leds blinks millis (pour comprendre comment millis marche)
2018-04-16 morse en millis (marche pas encore)
2018-04-16 keyboard + timer : class timer
2018-04-17 keyboard timer
2018-04-17 j'ai rajouté les explications du code
2018-04-19 keyboard + timer (machine a etat)
2018-04-19 keyboard+timer(bcp problemes)
2018-04-22 feature keyboard+timer
2018-04-28 morse réussi avec millis
2018-05-01 keyboard+timer+morse
    Some issues
2018-05-07 améliration page de garde
2018-05-08 schéma de la bombe
    [schéma complet.fzz]
2018-05-10 include lcd_part keyboard+timer (working)
2018-05-10 game_lauched variable (not working)
    [KeyboardModule.h, MorseModule.h, buzz.h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]
2018-05-10 Keyboard+Timer+Morse - Working !
    First version of the game who entirely works !
    Congrats !
2018-05-12 bombV1 finished (add beep timer) + correction manuel
    NB : Few tests have already been done ! Excel with modification + experimentation soon
    [KeyboardModule.h, MorseModule.h, mario_theme_buzzer.ino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]
2018-05-12 Arrangement + clean github readme
    [morse.fzz, schema_a_finir.fzz, test_bombe.xlsx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]
2018-05-14 Add few updates
    Beep end (death) + complicate SERIAL (programm + manuel) + few corrections
    [KeyboardModule.h, bomb_defusal_game_v1.ino, buzz.h]
2018-05-19 compte rendu + schéma
    [schema_a_finir - Copie.fzz, schema_a_finir.fzz]
2018-05-19 CR + schémas
    [morse.fzz, piano.fzz, schéma de la bombe - Copie.fzz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]
2018-05-19 compte rendu toujours
    [test_bombe.xlsx]
2018-05-22 modif accelerometre
